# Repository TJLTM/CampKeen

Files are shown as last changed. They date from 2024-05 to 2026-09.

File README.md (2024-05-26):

# CampKeen
An OpenSource RV monitoring hardware project. Currently i'm targeting my setup but leaving enough to adapt to other systems. This will allow a central place to monitor all of the various things in an RV and will be able to be integrated with an external system like Homeassistant (when I get to that it will have a separate Repo for the component) or custom setups. As well control some things around the RV. Like in this case, i have small holding tanks and to keep them from overflowing i have added waterpump and city (external water hook up control) in both the bathroom and in the kitchen. This does not have a wifi or ethernet capability. This is RS232 or USB (via the MEGA2560) device only. 

What this can monitor: 
1. Holding Tanks - Grey/Sewage via galvanic sensors (posts in the tank) these are the ones i'm using (https://www.amazon.com/gp/product/B07YVK2V2K/ref=ppx_yo_dt_b_search_asin_title?ie=UTF8&psc=1 and https://www.amazon.com/gp/product/B07SVDTHHG/ref=ppx_yo_dt_b_search_asin_title?ie=UTF8&psc=1)
2. Fresh water tank - Resistance (https://www.amazon.com/gp/product/B00Y831WPM/ref=ppx_yo_dt_b_asin_title_o07_s01?ie=UTF8&th=1&psc=1)
3. Camper Battery Voltage
4. Power/Energy Monitoring (https://github.com/CircuitSetup/Split-Single-Phase-Energy-Meter)
5. Tempetures around the RV especially and Fridge and Freezer (https://www.amazon.com/gp/product/B087NMHGX8/ref=ppx_yo_dt_b_asin_title_o07_s01?ie=UTF8&psc=1)
6. Generator Temps (https://www.amazon.com/gp/product/B071DVVZHC/ref=ppx_yo_dt_b_search_asin_title?ie=UTF8&psc=1) 
7. Generator Fuel Pressure (https://www.amazon.com/gp/product/B07N8SX347/ref=ppx_yo_dt_b_search_asin_title?ie=UTF8&th=1 becareful of these they may or may not be DOA or last only a few weeks depending i haven't found a good source that isn't a crap shoot) 
8. LPG tank level - No link as this is the original tank and sensor that came with the 1978 Pace Arrow it's resistence based but single wire it is similar to https://parts.unitedrv.com/products/remote-ohm-sender-lp-gas-tank-90-degree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

What this can control:
1. WaterPump
2. City Water Valve (https://www.amazon.com/gp/product/B07N6246YB/ref=ppx_yo_dt_b_asin_title_o05_s00?ie=UTF8&th=1)
I do this with push buttons (two one in the kitchen and one in the bathroom for my set up) with LEDs to let you know that the water is on. Be it the City Water or Tank Via the pump. 
i have also included a timer. that can be set for how long you would ike the water to remain on when either button is pressed.

Other Stuff
1. There are 6 spare outputs that can be used to control whatever you want 
2. Same goes for 6 spare inputs 
3. I2C output for an 20x4 LCD to display current status (https://www.amazon.com/gp/product/B07MTFDHXZ/ref=ppx_yo_dt_b_search_asin_title?ie=UTF8&psc=1)
4. Siren to alert when the tanks are full
5. Warning LED (This and the siren can be programmed for other items for warnings) 
6. 2 Spare Buffered ADCs with POTs 

Some Specs and Installation Notes: 
1. I designed this for 12Vdc systems only so i'm not sure if it would work on a 24Vdc system might. might not. 
2. The Inputs are buffered and you can just supply 12Vdc in as a logical 'On' 
3. Outputs, Althought technically you could power the waterpump directly off of the unit. this is not recommended. nor encouraged in any way, shape or form. These outputs are used to trigger remove 12Vdc relays like the following: https://www.summitracing.com/parts/pco-5591pt

currently working on https://github.com/TJLTM/CampKeen-HomeAssistant-Custom-Integration this may roll into a true python package later on to handle communication 

FUTURE: 
Better docs with installatioin pictures for my setup. 

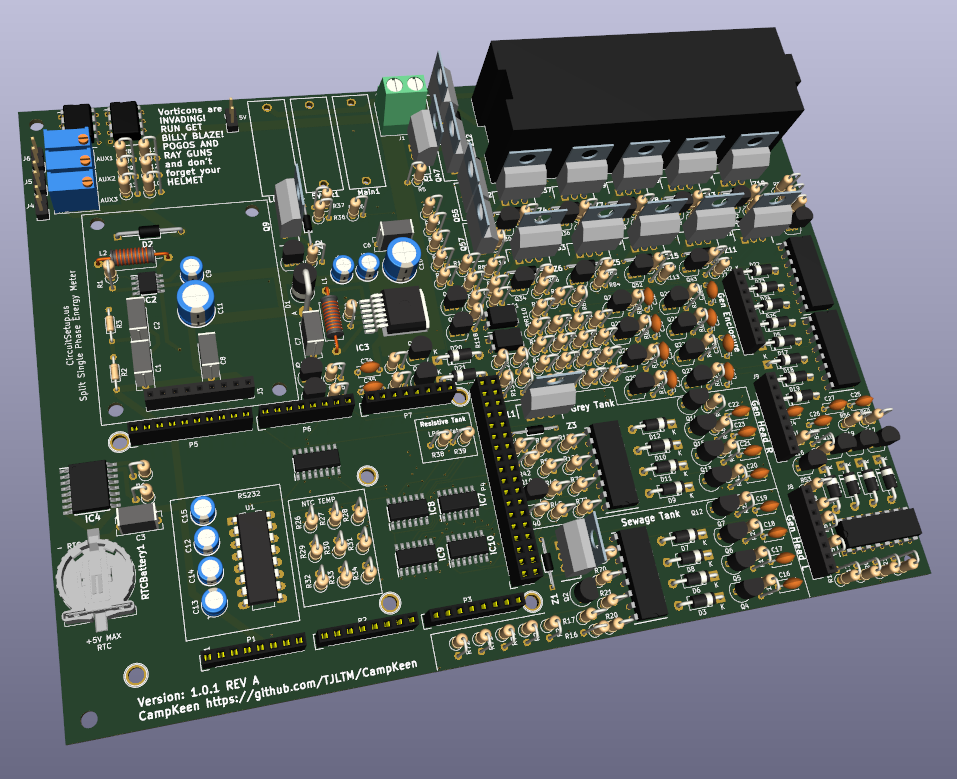
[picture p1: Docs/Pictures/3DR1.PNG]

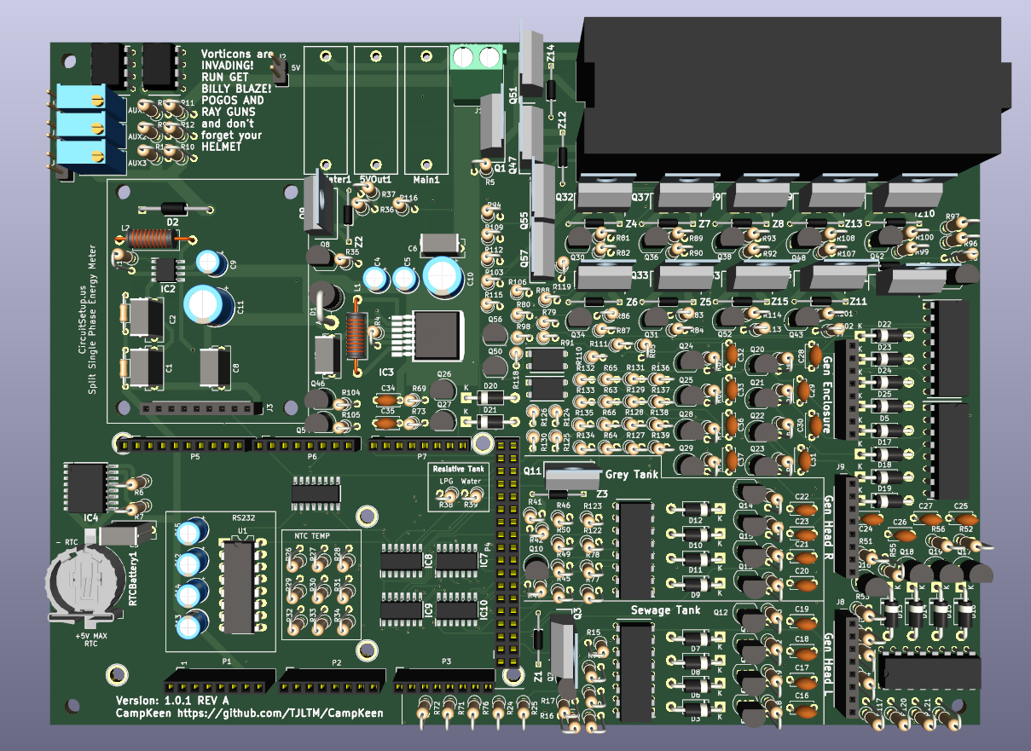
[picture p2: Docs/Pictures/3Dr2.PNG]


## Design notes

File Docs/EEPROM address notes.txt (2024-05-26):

Memory Address in EEPROM
1 - Units
2 - ACENMON on Boot - Data to be stored int 0,1
3 - 
4 - Streaming on Boot for USB Serial - Data to be sotred int 0,1
5 - Streaming on Boot for RS232 Serial - Data to be sotred int 0,1
6 - Energy Monitoring Frequency Data to be stored 50,60 
7 - Energy Monitoring Single Leg or Both Legs of 240 Data to be Stored 1,2
8 - Voltage Gain Upper Byte 
9 - Voltage Gain Lower Byte 
10 - CurrentGainCT1 Upper Byte
11 - CurrentGainCT1 Lower Byte
12 - CurrentGainCT2 Upper Byte
13 - CurrentGainCT2 Lower Byte
14 - PGAGain Upper Byte
15 - PGAGain Lower Byte
16 - WaterPumpSense on Boot - Data to be stored int 0,1
17 - WaterSourceOverRidee On Boot - Data to be stored in 0,1
18 - Kitchen Water Duration - Data to be stored Seconds in int (Upper Byte)
19 - Kitchen Water Duration - Data to be stored Seconds in int (Lower Byte)
20 - Bathroom Water Duration - Data to be stored Seconds in int (Upper Byte) 
21 - Bathroom Water Duration - Data to be stored Seconds in int (Lower Byte)

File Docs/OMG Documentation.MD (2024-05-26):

Introduction 

this project started with the lack of a way to monitor the systems within the RV I Have. this has lead to messes and headaches I no longer want to deal with and the fact that I'm somewhat smart (contrary to popular belief). I'm going to solve this problem with Electrical design and code. Mostly when I started this i wanted to be able to have a local system to monitor the various systems. NOw it's kind of grown into "I'm going to hook this up to xx so that i don't have to really do that much work and i can view it remotely". this is a mobile. techno nomad's dream come true. 

As I stated in the README. This is targeting my setup but if enough people like it then i'll work with you on getting your stuff setup. well until i loose interest if i'm not getting paid. Deal with it. but generally i'm pretty helpful because i enjoy this type of stuff. cause if i didn't i wouldn't be doing this. 

Table of contents
1. Sensors: Their Designs and Purposes 
2. FW workflows and quirks 
3. Installation information 

Sensors - Grey and Sewage Tanks 

Sensors - NTC Tempeture 

Sensors - Water Tank

Sensors - LPG Tank 

Sensors - Fuel Pressure 

Sensors - Contact inputs 

Sensors -

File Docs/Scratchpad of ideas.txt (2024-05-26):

remove LCD backlight control and dimming local to the LCD (offload from campkeen)
get serial Port3 free as to be used for ESP32 connection 
look at tanks and see if holding tanks can be consolidated to one fet for power 
if i have to free up space on the PCB, look into removing some of the hex inverters (SN7404)

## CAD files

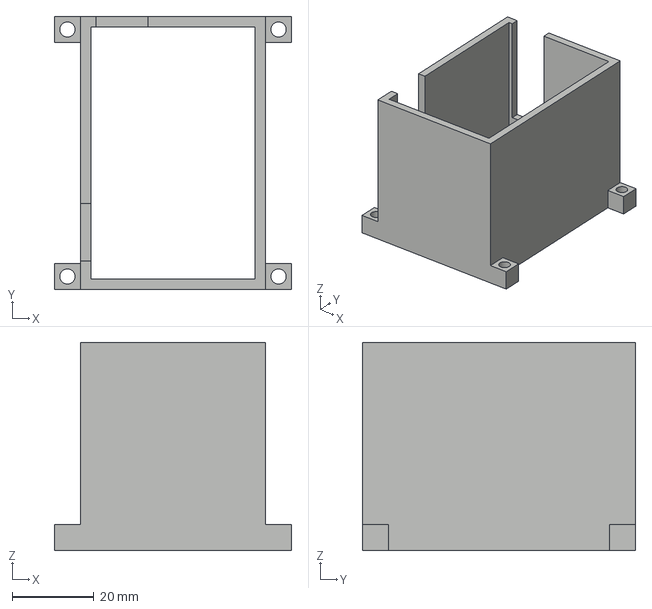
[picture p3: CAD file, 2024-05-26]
3D Parts/Transformer 157041 mount.FCStd
57.9 x 66.7 x 50.8 mm

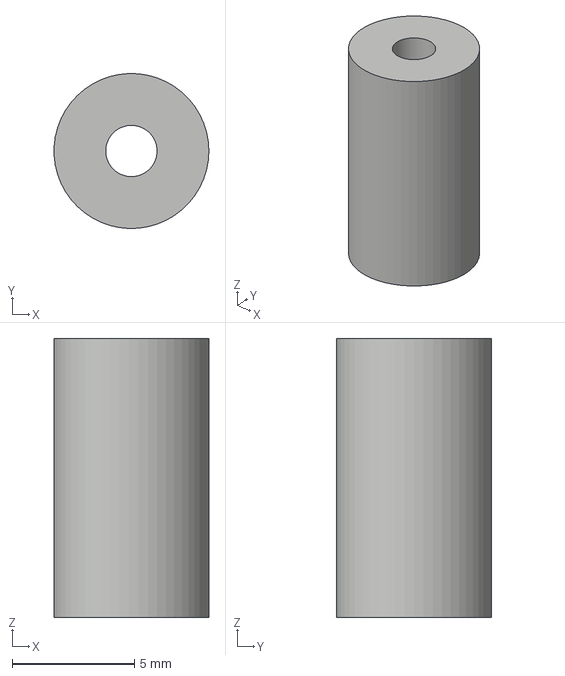
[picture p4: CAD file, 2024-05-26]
3D Parts/EnergyMonitorSpacer.FCStd
6.34 x 6.35 x 11.4 mm

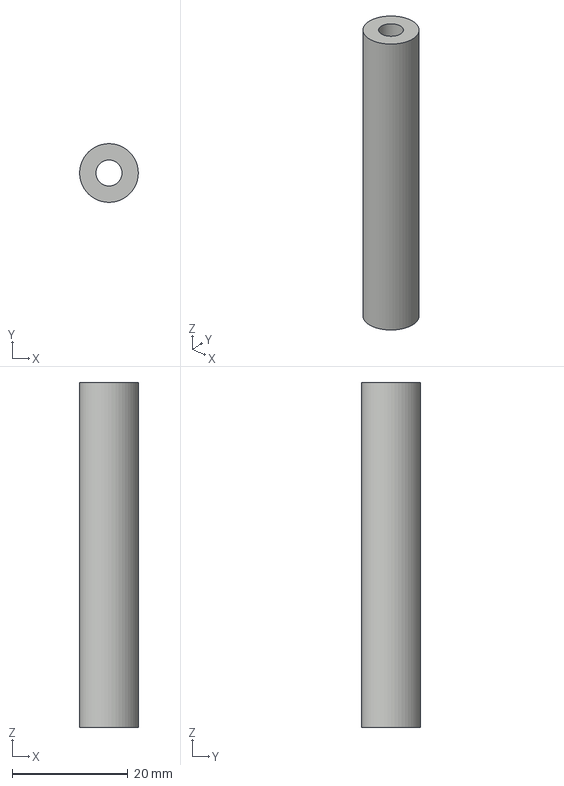
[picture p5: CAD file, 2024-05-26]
3D Parts/PanelStandOff.FCStd
10.2 x 10.2 x 59.7 mm

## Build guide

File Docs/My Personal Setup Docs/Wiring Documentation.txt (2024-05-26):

Water Pump
-- White -- Water pump sense 
-- Green -- Water Pump Relay
-- black -- NC
-- red -- NC 

Sewage/Grey 
-- Blue --1/4
-- Brown -- 1/2
-- Green -- 3/4
-- White - Full
-- Red/Black -- 12v Power

Bathroom 
-- Red -- LED Positive 
-- White -- Button Positive
-- Green -- Button input to CampKeen
-- Black -- LED GND

Kitchen 
-- Red -- LED Positive
-- Black -- LED GND
-- White -- Button Positive
-- Green -- Button input to CampKeen

LCD/Control panel 
-- warning LED -- brown/white
-- Alarm LED/Siren -- brown
-- water source selection -- green 
-- Alarm Reset -- orange
-- Enable LCD -- green/white
-- I2C SDA -- blue
-- I2C SCL -- blue/white
-- 5V -- orange/white

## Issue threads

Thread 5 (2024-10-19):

swap power to daughter boards

TJLTM, 2024-10-19:

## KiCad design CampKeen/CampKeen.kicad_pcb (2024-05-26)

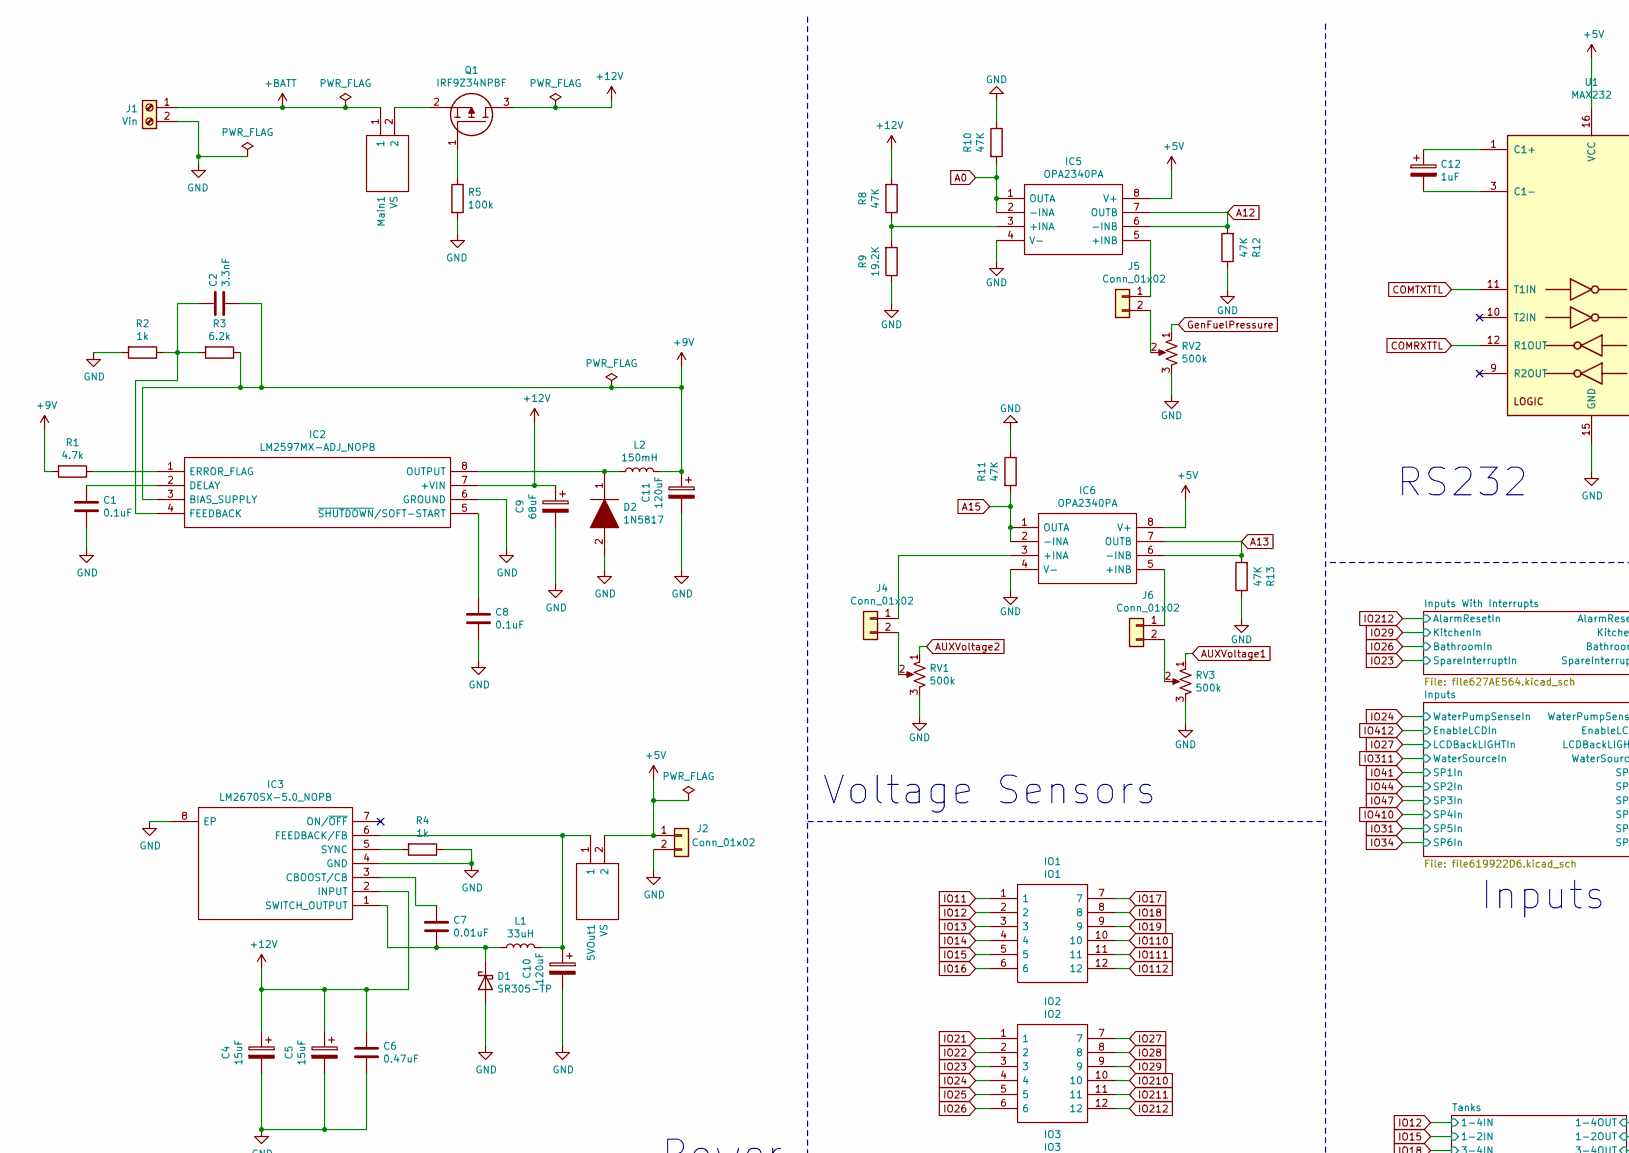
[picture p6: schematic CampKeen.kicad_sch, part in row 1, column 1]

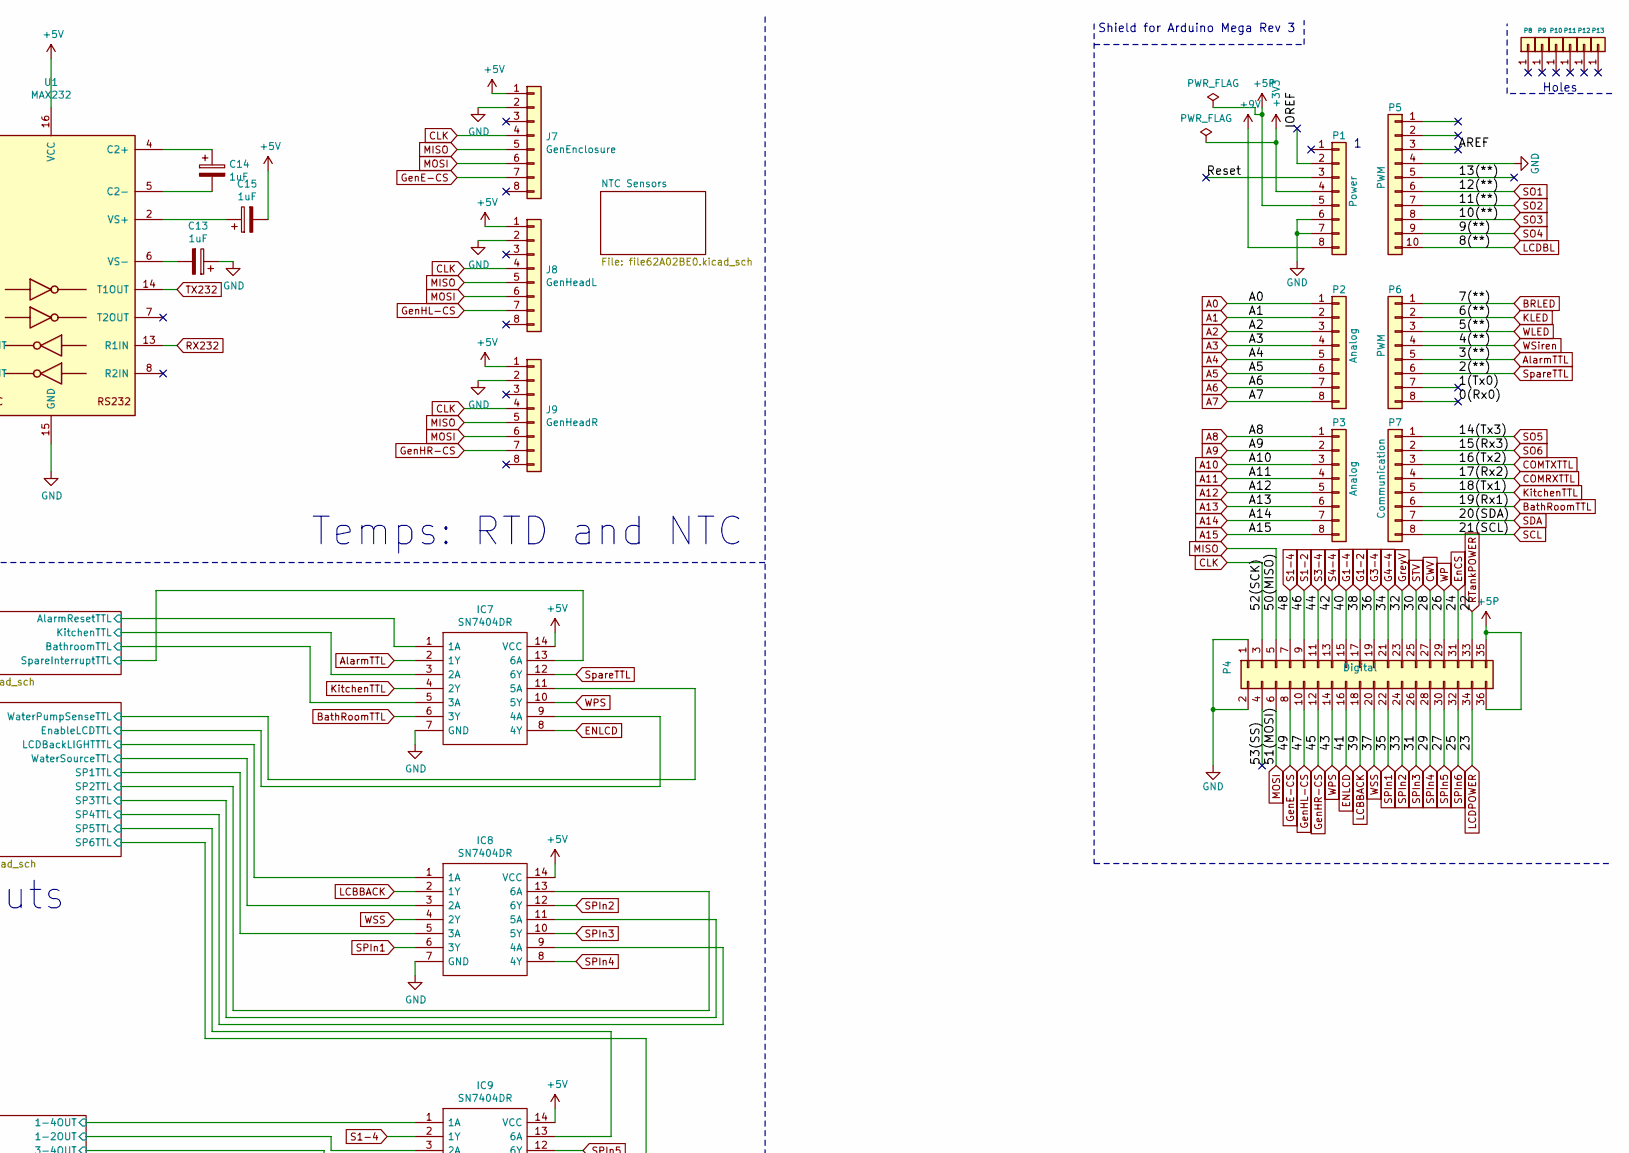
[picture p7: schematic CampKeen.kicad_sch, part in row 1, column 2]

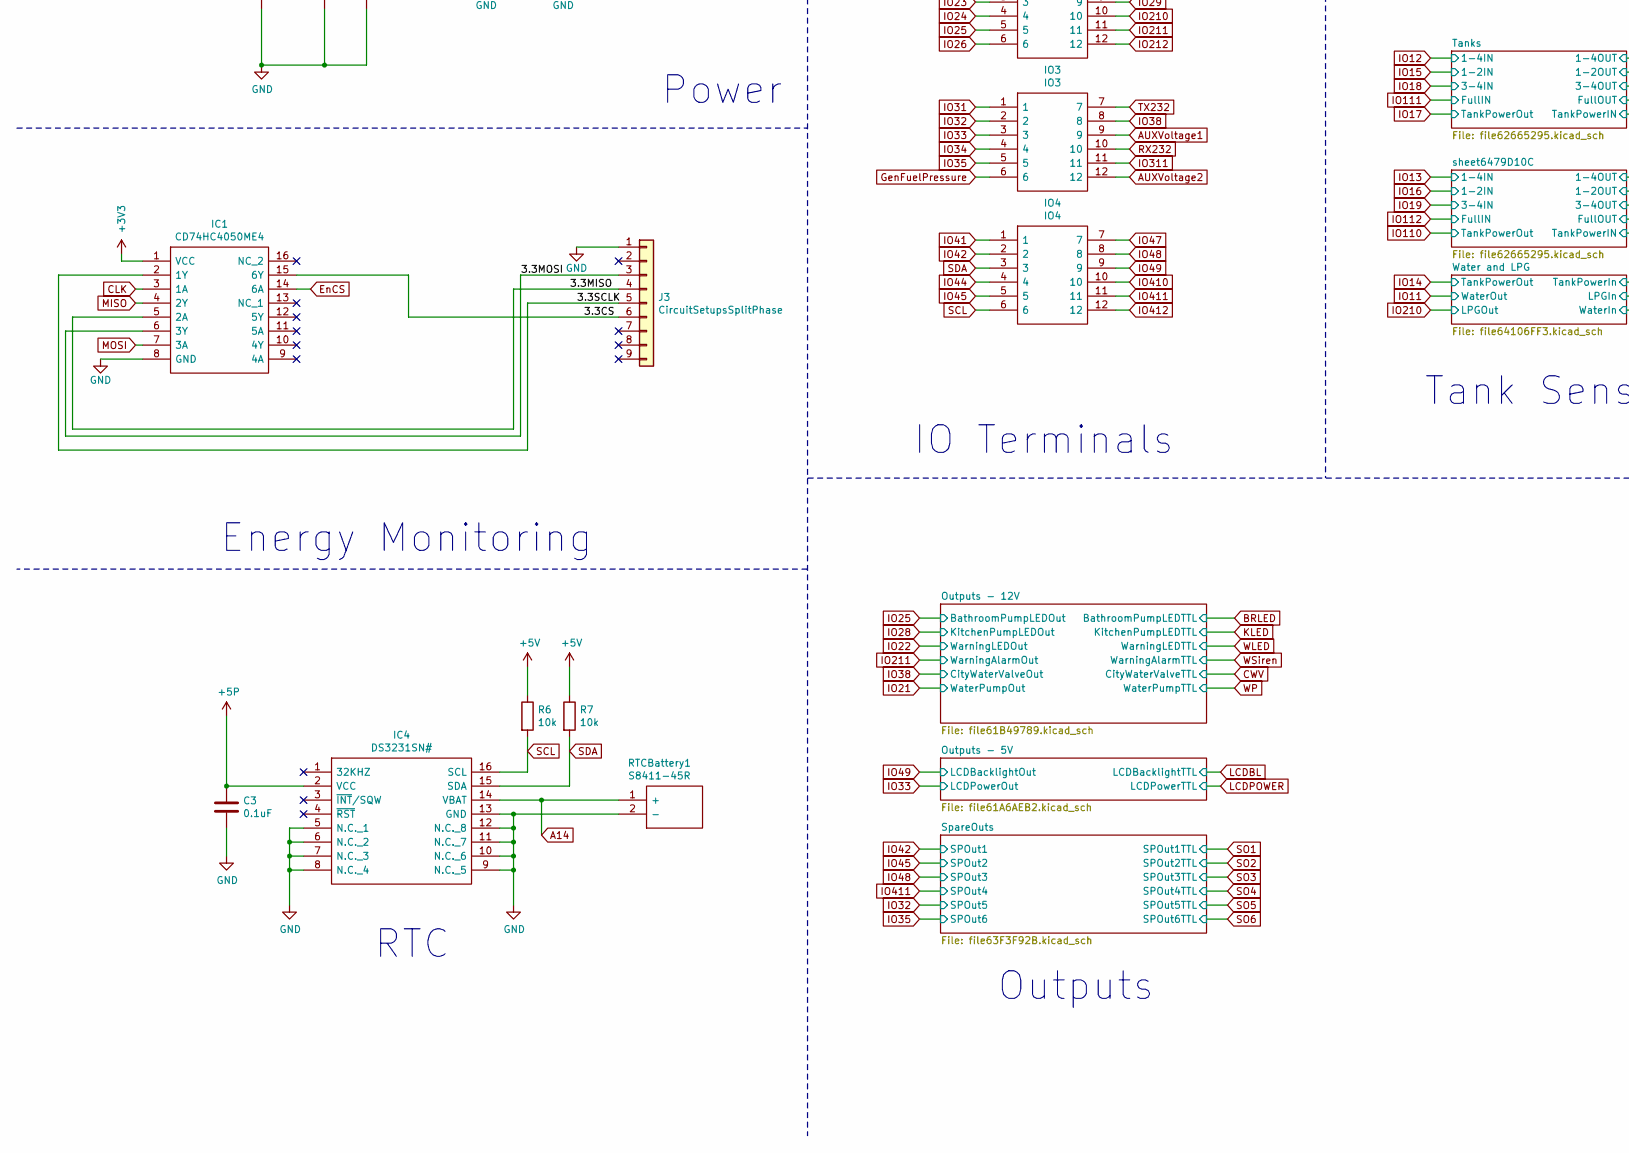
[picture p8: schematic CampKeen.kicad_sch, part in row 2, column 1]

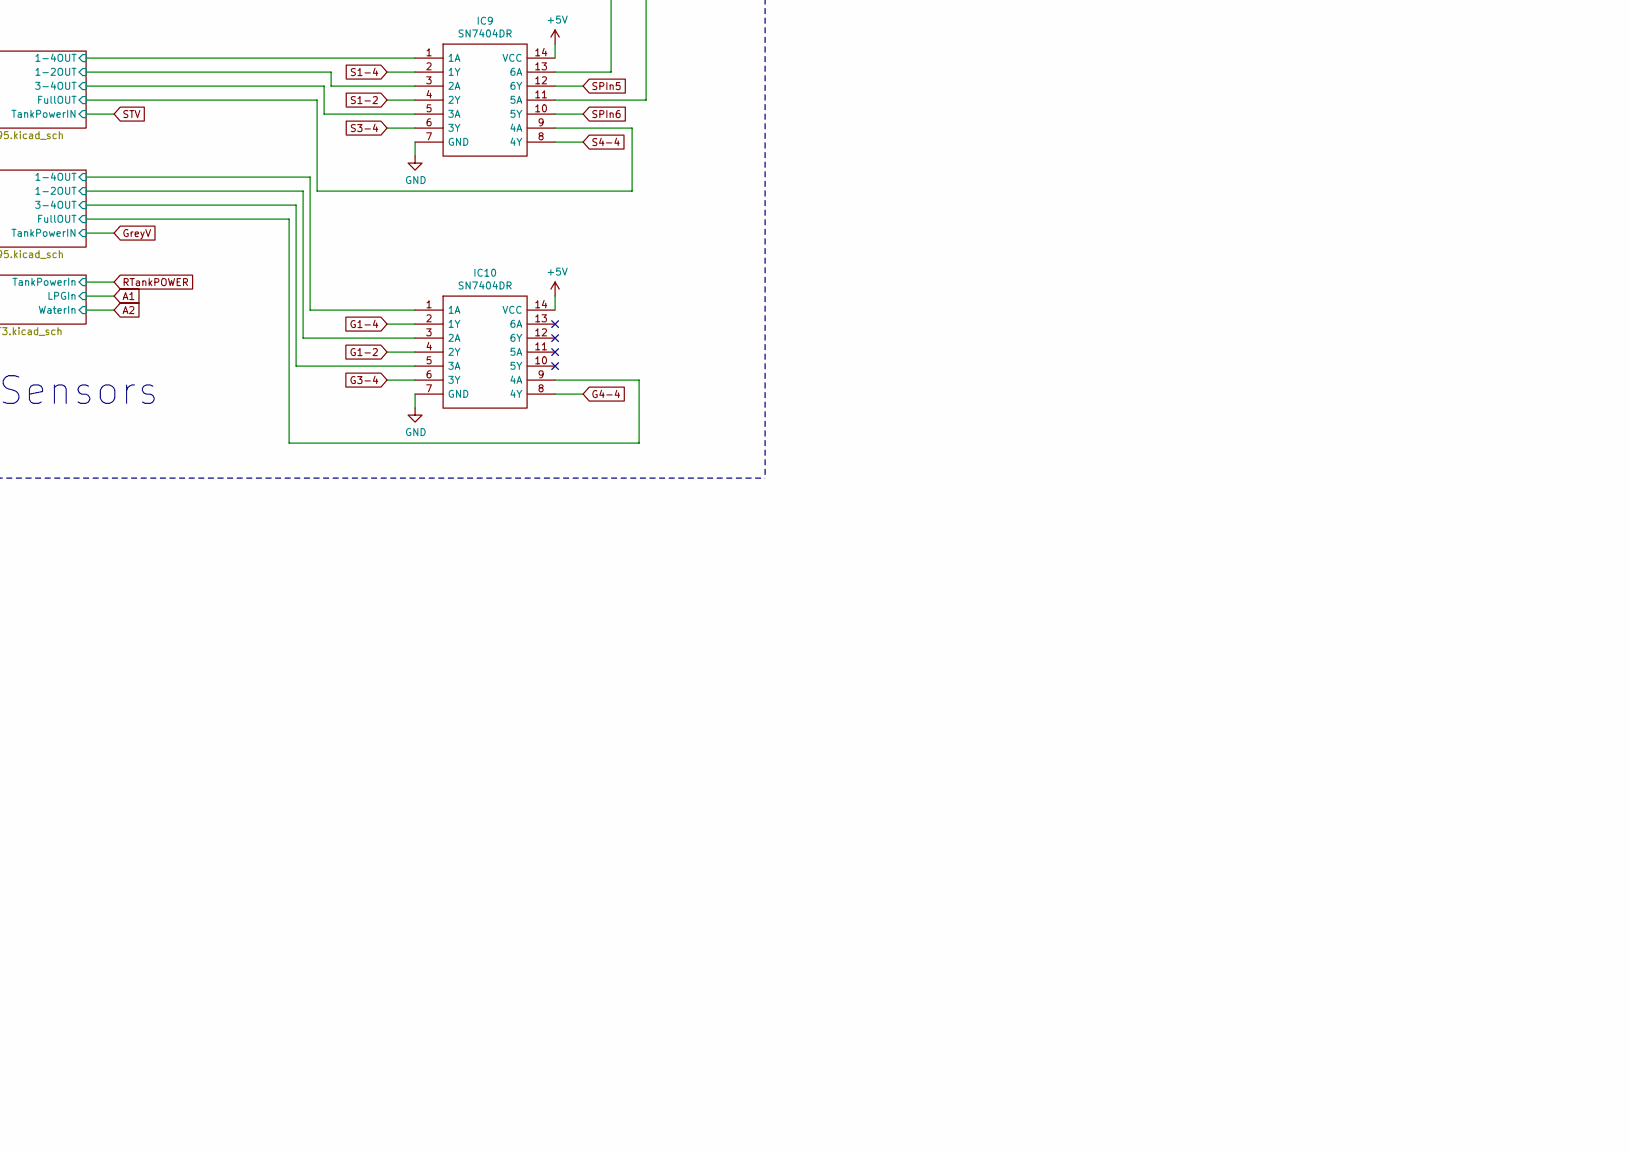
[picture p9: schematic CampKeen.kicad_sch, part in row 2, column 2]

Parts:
5VOut1: VS; BK_HTC-15M; Mouser Part Number 504-HTC-15M
C1, C3, C8: 0.1uF; C_Rect_L9.0mm_W3.6mm_P7.50mm_MKT
C2: 3.3nF; C_Rect_L9.0mm_W3.6mm_P7.50mm_MKT
C4, C5: 15uF; CP_Radial_D5.0mm_P2.50mm
C6: 0.47uF; C_Rect_L9.0mm_W3.6mm_P7.50mm_MKT
C7: 0.01uF; C_Rect_L9.0mm_W3.6mm_P7.50mm_MKT
C9: 68uF; CP_Radial_D5.0mm_P2.50mm
C10, C11: 120uF; CP_Radial_D8.0mm_P5.00mm
C12, C13, C14, C15: 1uF; CP_Radial_D5.0mm_P2.50mm
D1: SR305-TP; D_DO-201AD_P5.08mm_Vertical_AnodeUp
D2: 1N5817; DIOAD1414W86L464D238; Mouser Part Number 511-1N5817
IC1: CD74HC4050ME4; SOIC127P600X175-16N; Mouser Part Number 595-CD74HC4050ME4
IC2: LM2597MX-ADJ_NOPB; SOIC127P600X175-8N; Mouser Part Number 926-LM2597MXADJNOPB
IC3: LM2670SX-5.0_NOPB; LM2670SX50NOPB; Mouser Part Number 926-LM2670SX50NOPB
IC4: DS3231SN#; SOIC127P1032X265-16N; Mouser Part Number 700-DS3231SN#
IC5, IC6: OPA2340PA; DIP794W53P254L959H508Q8N; Mouser Part Number 595-OPA2340PA
IC7, IC8, IC9, IC10: SN7404DR; SOIC127P600X175-14N; Mouser Part Number 595-SN7404DR
IO1: IO1; 1727751; Mouser Part Number 651-1727751
IO2: IO2; 1727751; Mouser Part Number 651-1727751
IO3: IO3; 1727751; Mouser Part Number 651-1727751
IO4: IO4; 1727751; Mouser Part Number 651-1727751
J1: Vin; TerminalBlock_Phoenix_MKDS-1,5-2-5.08_1x02_P5.08mm_Horizont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
J2, J4, J5, J6: Conn_01x02; PinHeader_1x02_P2.54mm_Vertical
J3: CircuitSetupsSplitPhase; PinSocket_1x09_P2.54mm_Vertical
J7: GenEnclosure; PinSocket_1x08_P2.54mm_Vertical
J8: GenHeadL; PinSocket_1x08_P2.54mm_Vertical
J9: GenHeadR; PinSocket_1x08_P2.54mm_Vertical
L1: 33uH; L_Axial_L9.5mm_D4.0mm_P15.24mm_Horizontal_Fastron_SMCC
L2: 150mH; L_Axial_L9.5mm_D4.0mm_P15.24mm_Horizontal_Fastron_SMCC
Main1: VS; BK_HTC-15M; Mouser Part Number 504-HTC-15M
P1: Power; Socket_Strip_Arduino_1x08
P2, P3: Analog; Socket_Strip_Arduino_1x08
P4: Digital; Socket_Strip_Arduino_2x18
P5: PWM; Socket_Strip_Arduino_1x10
P6: PWM; Socket_Strip_Arduino_1x08
P7: Communication; Socket_Strip_Arduino_1x08
P8, P9, P10, P11, P12, P13: CONN_01X01; Arduino_1pin
Q1: IRF9Z34NPBF; TO254P469X1042X1967-3P; Mouser Part Number 942-IRF9Z34NPBF
R1: 4.7k; R_Axial_DIN0207_L6.3mm_D2.5mm_P2.54mm_Vertical
R2: 1k; R_Axial_DIN0204_L3.6mm_D1.6mm_P7.62mm_Horizontal
R3: 6.2k; R_Axial_DIN0204_L3.6mm_D1.6mm_P7.62mm_Horizontal
R4: 1k; R_Axial_DIN0207_L6.3mm_D2.5mm_P2.54mm_Vertical
R5: 100k; R_Axial_DIN0207_L6.3mm_D2.5mm_P2.54mm_Vertical
R6, R7: 10k; R_Axial_DIN0207_L6.3mm_D2.5mm_P2.54mm_Vertical
R8, R10, R11, R12, R13: 47K; R_Axial_DIN0207_L6.3mm_D2.5mm_P2.54mm_Vertical
R9: 19.2K; R_Axial_DIN0207_L6.3mm_D2.5mm_P2.54mm_Vertical
RTCBattery1: S8411-45R; S8411-45R_1; Mouser Part Number 855-S8411-45R
RV1, RV2, RV3: 500k; Potentiometer_Bourns_3296W_Vertical
U1: MAX232; DIP-16_W7.62mm_LongPads

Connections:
+3V3: IC1.1 (VCC), P1.4
+5P: C3.1, IC4.2 (VCC), P1.5, P4.35, P4.36
+5V: 5VOut1.2, C15.2, IC5.8 (V+), IC6.8 (V+), IC7.14 (VCC), IC8.14 (VCC), IC9.14 (VCC), IC10.14 (VCC), J2.1, J7.1, J8.1, J9.1, R6.1, R7.1, U1.16 (VCC); also elsewhere on the board
+9V: C2.2, C11.1, IC2.3 (BIAS_SUPPLY), L2.2, P1.8, R1.2, R3.1
+12V: C4.1, C5.1, C6.1, C9.1, IC2.7 (+VIN), IC3.2 (INPUT), Q1.3, R8.2; also elsewhere on the board
+BATT: J1.1, Main1.1; also elsewhere on the board
/0(Rx0): P6.8
/1(Tx0): P6.7
/3.3CS: IC1.15 (6Y), J3.6
/3.3MISO: IC1.5 (2A), J3.4
/3.3MOSI: IC1.6 (3Y), J3.3
/3.3SCLK: IC1.2 (1Y), J3.5
/13(**): P5.5
/53(SS): P4.4
/AREF: P5.3
/IOREF: P1.2
/Inputs With Interrupts/AlarmResetTTL: IC7.1 (1A); also elsewhere on the board
/Inputs With Interrupts/BathroomTTL: IC7.5 (3A); also elsewhere on the board
/Inputs With Interrupts/KitchenTTL: IC7.3 (2A); also elsewhere on the board
/Inputs With Interrupts/SpareInterruptTTL: IC7.13 (6A); also elsewhere on the board
/Inputs/EnableLCDTTL: IC7.9 (4A); also elsewhere on the board
/Inputs/LCDBackLIGHTTTL: IC8.1 (1A); also elsewhere on the board
/Inputs/SP1TTL: IC8.5 (3A); also elsewhere on the board
/Inputs/SP2TTL: IC8.13 (6A); also elsewhere on the board
/Inputs/SP3TTL: IC8.11 (5A); also elsewhere on the board
/Inputs/SP4TTL: IC8.9 (4A); also elsewhere on the board
/Inputs/SP5TTL: IC9.13 (6A); also elsewhere on the board
/Inputs/SP6TTL: IC9.11 (5A); also elsewhere on the board
/Inputs/WaterPumpSenseTTL: IC7.11 (5A); also elsewhere on the board
/Inputs/WaterSourceTTL: IC8.3 (2A); also elsewhere on the board
/Reset: P1.3
/Tanks/1-2OUT: IC9.3 (2A); also elsewhere on the board
/Tanks/1-4OUT: IC9.1 (1A); also elsewhere on the board
/Tanks/3-4OUT: IC9.5 (3A); also elsewhere on the board
/Tanks/FullOUT: IC9.9 (4A); also elsewhere on the board
/sheet6479D10C/1-2OUT: IC10.3 (2A); also elsewhere on the board
/sheet6479D10C/1-4OUT: IC10.1 (1A); also elsewhere on the board
/sheet6479D10C/3-4OUT: IC10.5 (3A); also elsewhere on the board
/sheet6479D10C/FullOUT: IC10.9 (4A); also elsewhere on the board
A0: IC5.1 (OUTA), IC5.2 (-INA), P2.1, R10.2
A1: IO2.10, P2.2; also elsewhere on the board
A2: IO1.1, P2.3; also elsewhere on the board
A3: P2.4; also elsewhere on the board
A4: P2.5; also elsewhere on the board
A5: P2.6; also elsewhere on the board
A6: P2.7; also elsewhere on the board
A7: P2.8; also elsewhere on the board
A8: P3.1; also elsewhere on the board
A9: P3.2; also elsewhere on the board
A10: P3.3; also elsewhere on the board
A11: P3.4; also elsewhere on the board
A12: IC5.6 (-INB), IC5.7 (OUTB), P3.5, R12.2
A13: IC6.6 (-INB), IC6.7 (OUTB), P3.6, R13.2
A14: IC4.14 (VBAT), P3.7, RTCBattery1.1 (+)
A15: IC6.1 (OUTA), IC6.2 (-INA), P3.8, R11.2
AUXVoltage1: IO3.9, RV3.1
AUXVoltage2: IO3.12, RV1.1
AlarmTTL: IC7.2 (1Y), P6.5
BRLED: P6.1; also elsewhere on the board
BathRoomTTL: IC7.6 (3Y), P7.6
CLK: IC1.3 (1A), J7.4, J8.4, J9.4, P4.3
COMRXTTL: P7.4, U1.12 (R1OUT)
COMTXTTL: P7.3, U1.11 (T1IN)
CWV: P4.27; also elsewhere on the board
ENLCD: IC7.8 (4Y), P4.16
EnCS: IC1.14 (6A), P4.31
G1-2: IC10.4 (2Y), P4.17
G1-4: IC10.2 (1Y), P4.15
G3-4: IC10.6 (3Y), P4.19
G4-4: IC10.8 (4Y), P4.21
GND: C1.2, C3.2, C4.2, C5.2, C6.2, C8.2, C9.2, C10.2, C11.2, C13.1, D1.2 (A), D2.2, IC1.8 (GND), IC2.6 (GROUND), IC3.4 (GND), IC3.8 (EP), IC4.5 (N.C._1), IC4.6 (N.C._2), IC4.7 (N.C._3), IC4.8 (N.C._4), IC4.9 (N.C._5), IC4.10 (N.C._6), IC4.11 (N.C._7), IC4.12 (N.C._8), IC4.13 (GND), IC5.4 (V-), IC6.4 (V-), IC7.7 (GND), IC8.7 (GND), IC9.7 (GND), IC10.7 (GND), J1.2, J2.2, J3.1, J7.2, J8.2, J9.2, P1.6, P1.7, P4.1, P4.2, P5.4, R2.2, R4.1, R5.2, R9.1, R10.1, R11.1, R12.1, R13.1, RTCBattery1.2 (-), RV1.3, RV2.3, RV3.3, U1.15 (GND); also elsewhere on the board
GenE-CS: J7.7, P4.8
GenFuelPressure: IO3.6, RV2.1
GenHL-CS: J8.7, P4.10
GenHR-CS: J9.7, P4.12
GreyV: P4.23; also elsewhere on the board
IO12: IO1.2; also elsewhere on the board
IO13: IO1.3; also elsewhere on the board
IO14: IO1.4; also elsewhere on the board
IO15: IO1.5; also elsewhere on the board
IO16: IO1.6; also elsewhere on the board
IO17: IO1.7; also elsewhere on the board
IO18: IO1.8; also elsewhere on the board
IO19: IO1.9; also elsewhere on the board
IO21: IO2.1; also elsewhere on the board
IO22: IO2.2; also elsewhere on the board
IO23: IO2.3; also elsewhere on the board
IO24: IO2.4; also elsewhere on the board
IO25: IO2.5; also elsewhere on the board
IO26: IO2.6; also elsewhere on the board
IO27: IO2.7; also elsewhere on the board
IO28: IO2.8; also elsewhere on the board
IO29: IO2.9; also elsewhere on the board
IO31: IO3.1; also elsewhere on the board
IO32: IO3.2; also elsewhere on the board
IO33: IO3.3; also elsewhere on the board
IO34: IO3.4; also elsewhere on the board
IO35: IO3.5; also elsewhere on the board
IO38: IO3.8; also elsewhere on the board
IO41: IO4.1; also elsewhere on the board
IO42: IO4.2; also elsewhere on the board
IO44: IO4.4; also elsewhere on the board
IO45: IO4.5; also elsewhere on the board
IO47: IO4.7; also elsewhere on the board
IO48: IO4.8; also elsewhere on the board
IO49: IO4.9; also elsewhere on the board
IO110: IO1.10; also elsewhere on the board
IO111: IO1.11; also elsewhere on the board
IO112: IO1.12; also elsewhere on the board
IO211: IO2.11; also elsewhere on the board
IO212: IO2.12; also elsewhere on the board
IO311: IO3.11; also elsewhere on the board
IO410: IO4.10; also elsewhere on the board
IO411: IO4.11; also elsewhere on the board
IO412: IO4.12; also elsewhere on the board
KLED: P6.2; also elsewhere on the board
KitchenTTL: IC7.4 (2Y), P7.5
LCBBACK: IC8.2 (1Y), P4.18
LCDBL: P5.10; also elsewhere on the board
LCDPOWER: P4.34; also elsewhere on the board
MISO: IC1.4 (2Y), J7.5, J8.5, J9.5, P4.5
MOSI: IC1.7 (3A), J7.6, J8.6, J9.6, P4.6
unnamed: 5VOut1.1, C10.1, IC3.6 (FEEDBACK/FB), L1.2
unnamed: C1.1, IC2.2 (DELAY)
unnamed: C2.1, IC2.4 (FEEDBACK), R2.1, R3.2
unnamed: C7.1, IC3.3 (CBOOST/CB)
unnamed: C7.2, D1.1 (K), IC3.1 (SWITCH_OUTPUT), L1.1
unnamed: C8.1, IC2.5 (~SHUTDOWN/SOFT-START)
unnamed: C12.1, U1.1 (C1+)
unnamed: C12.2, U1.3 (C1-)
unnamed: C13.2, U1.6 (VS-)
unnamed: C14.1, U1.4 (C2+)
unnamed: C14.2, U1.5 (C2-)
unnamed: C15.1, U1.2 (VS+)
unnamed: D2.1, IC2.8 (OUTPUT), L2.1
unnamed: IC2.1 (ERROR_FLAG), R1.1
unnamed: IC3.5 (SYNC), R4.2
unnamed: IC5.3 (+INA), R8.1, R9.2
unnamed: IC5.5 (+INB), J5.1
unnamed: IC6.3 (+INA), J4.1
unnamed: IC6.5 (+INB), J6.1
unnamed: J4.2, RV1.2
unnamed: J5.2, RV2.2
unnamed: J6.2, RV3.2
unnamed: Main1.2, Q1.2
unnamed: Q1.1, R5.1
RTankPOWER: P4.33; also elsewhere on the board
RX232: IO3.10, U1.13 (R1IN)
S1-2: IC9.4 (2Y), P4.9
S1-4: IC9.2 (1Y), P4.7
S3-4: IC9.6 (3Y), P4.11
S4-4: IC9.8 (4Y), P4.13
SCL: IC4.16 (SCL), IO4.6, P7.8, R6.2
SDA: IC4.15 (SDA), IO4.3, P7.7, R7.2
SO1: P5.6; also elsewhere on the board
SO2: P5.7; also elsewhere on the board
SO3: P5.8; also elsewhere on the board
SO4: P5.9; also elsewhere on the board
SO5: P7.1; also elsewhere on the board
SO6: P7.2; also elsewhere on the board
SPIn1: IC8.6 (3Y), P4.22
SPIn2: IC8.12 (6Y), P4.24
SPIn3: IC8.10 (5Y), P4.26
SPIn4: IC8.8 (4Y), P4.28
SPIn5: IC9.12 (6Y), P4.30
SPIn6: IC9.10 (5Y), P4.32
STV: P4.25; also elsewhere on the board
SpareTTL: IC7.12 (6Y), P6.6
TX232: IO3.7, U1.14 (T1OUT)
WLED: P6.3; also elsewhere on the board
WP: P4.29; also elsewhere on the board
WPS: IC7.10 (5Y), P4.14
WSS: IC8.4 (2Y), P4.20
WSiren: P6.4; also elsewhere on the board

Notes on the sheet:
Outputs
Energy Monitoring
Temps: RTD and NTC
RTC
Holes
Tank Sensors
Voltage Sensors
Shield for Arduino Mega Rev 3
Inputs
Power
RS232
IO Terminals

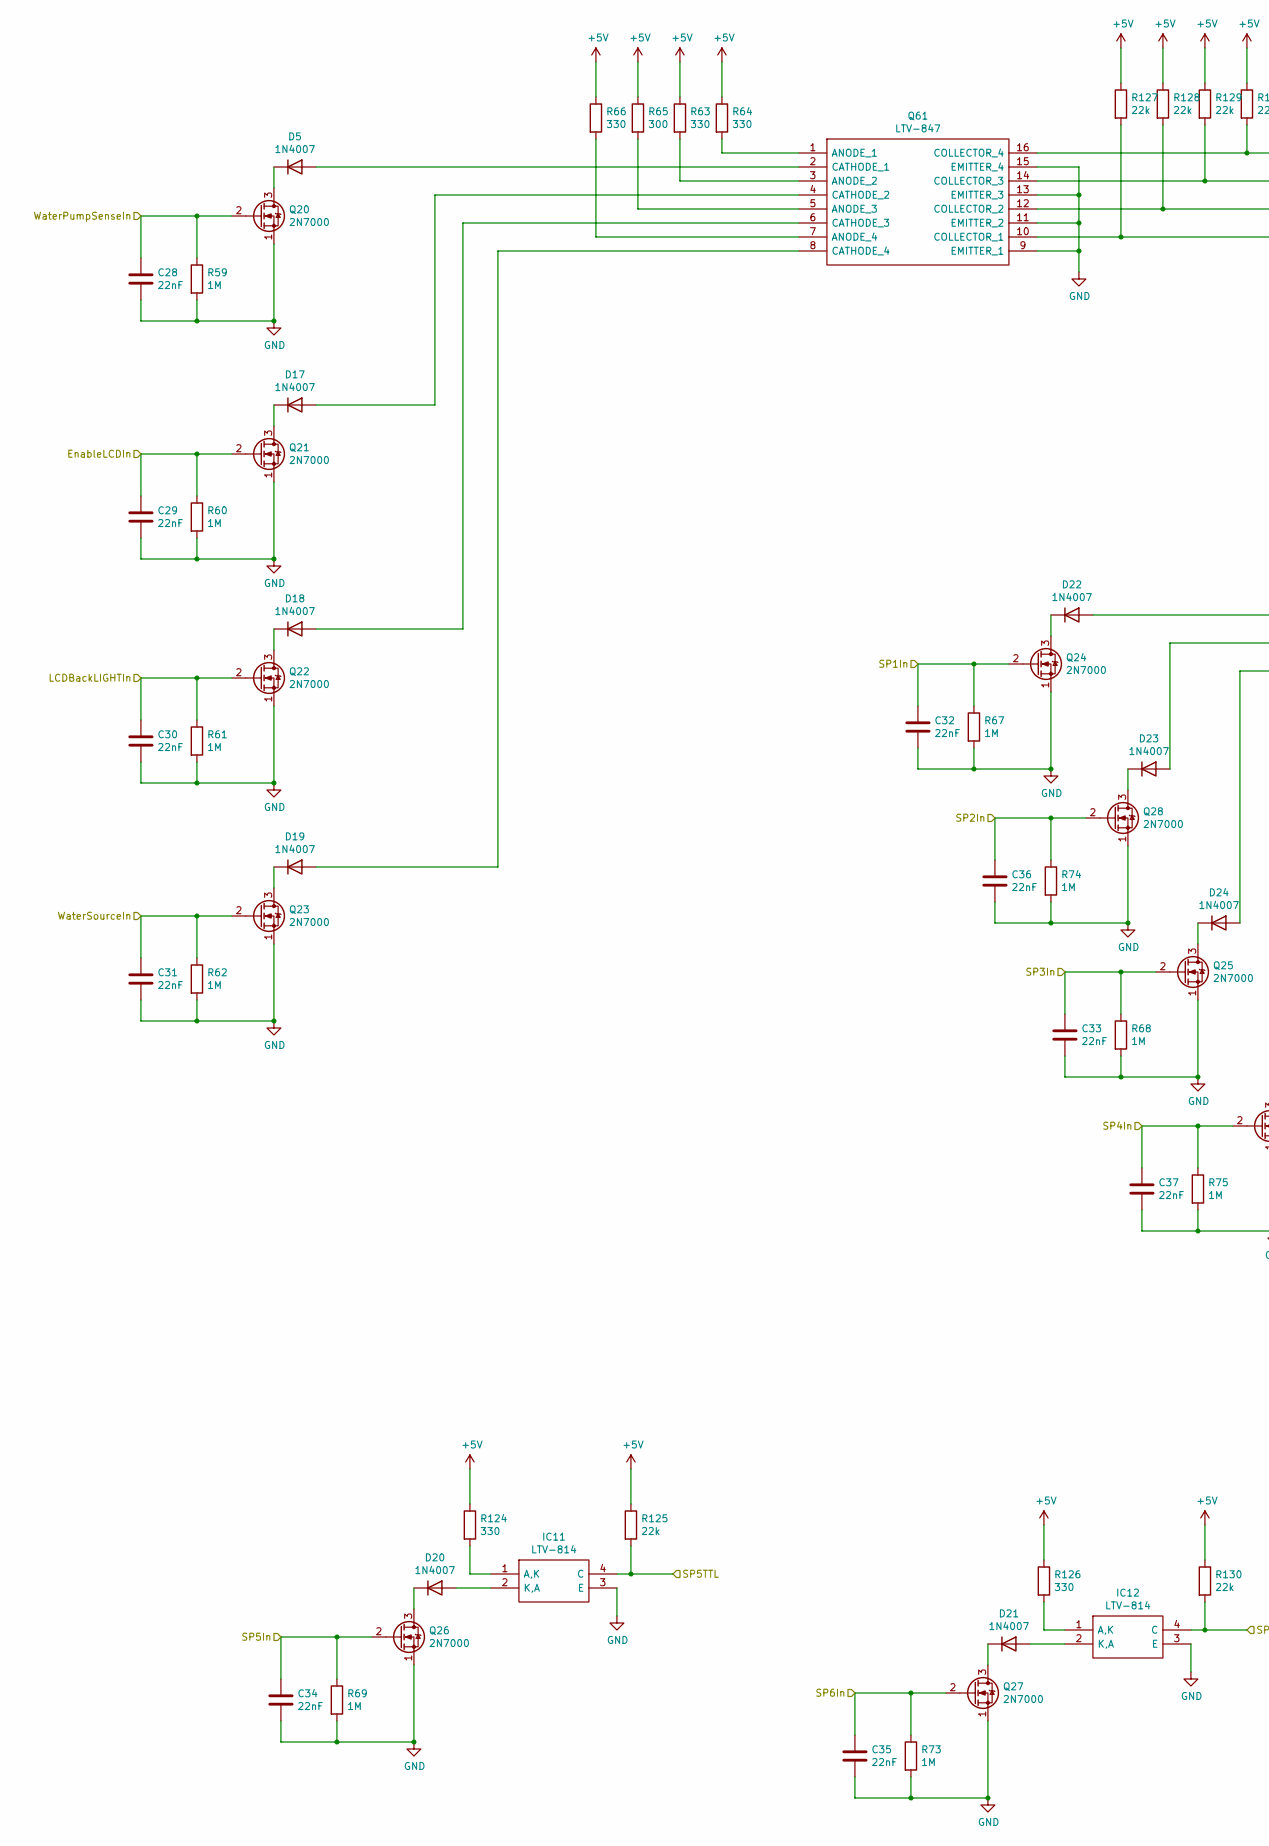
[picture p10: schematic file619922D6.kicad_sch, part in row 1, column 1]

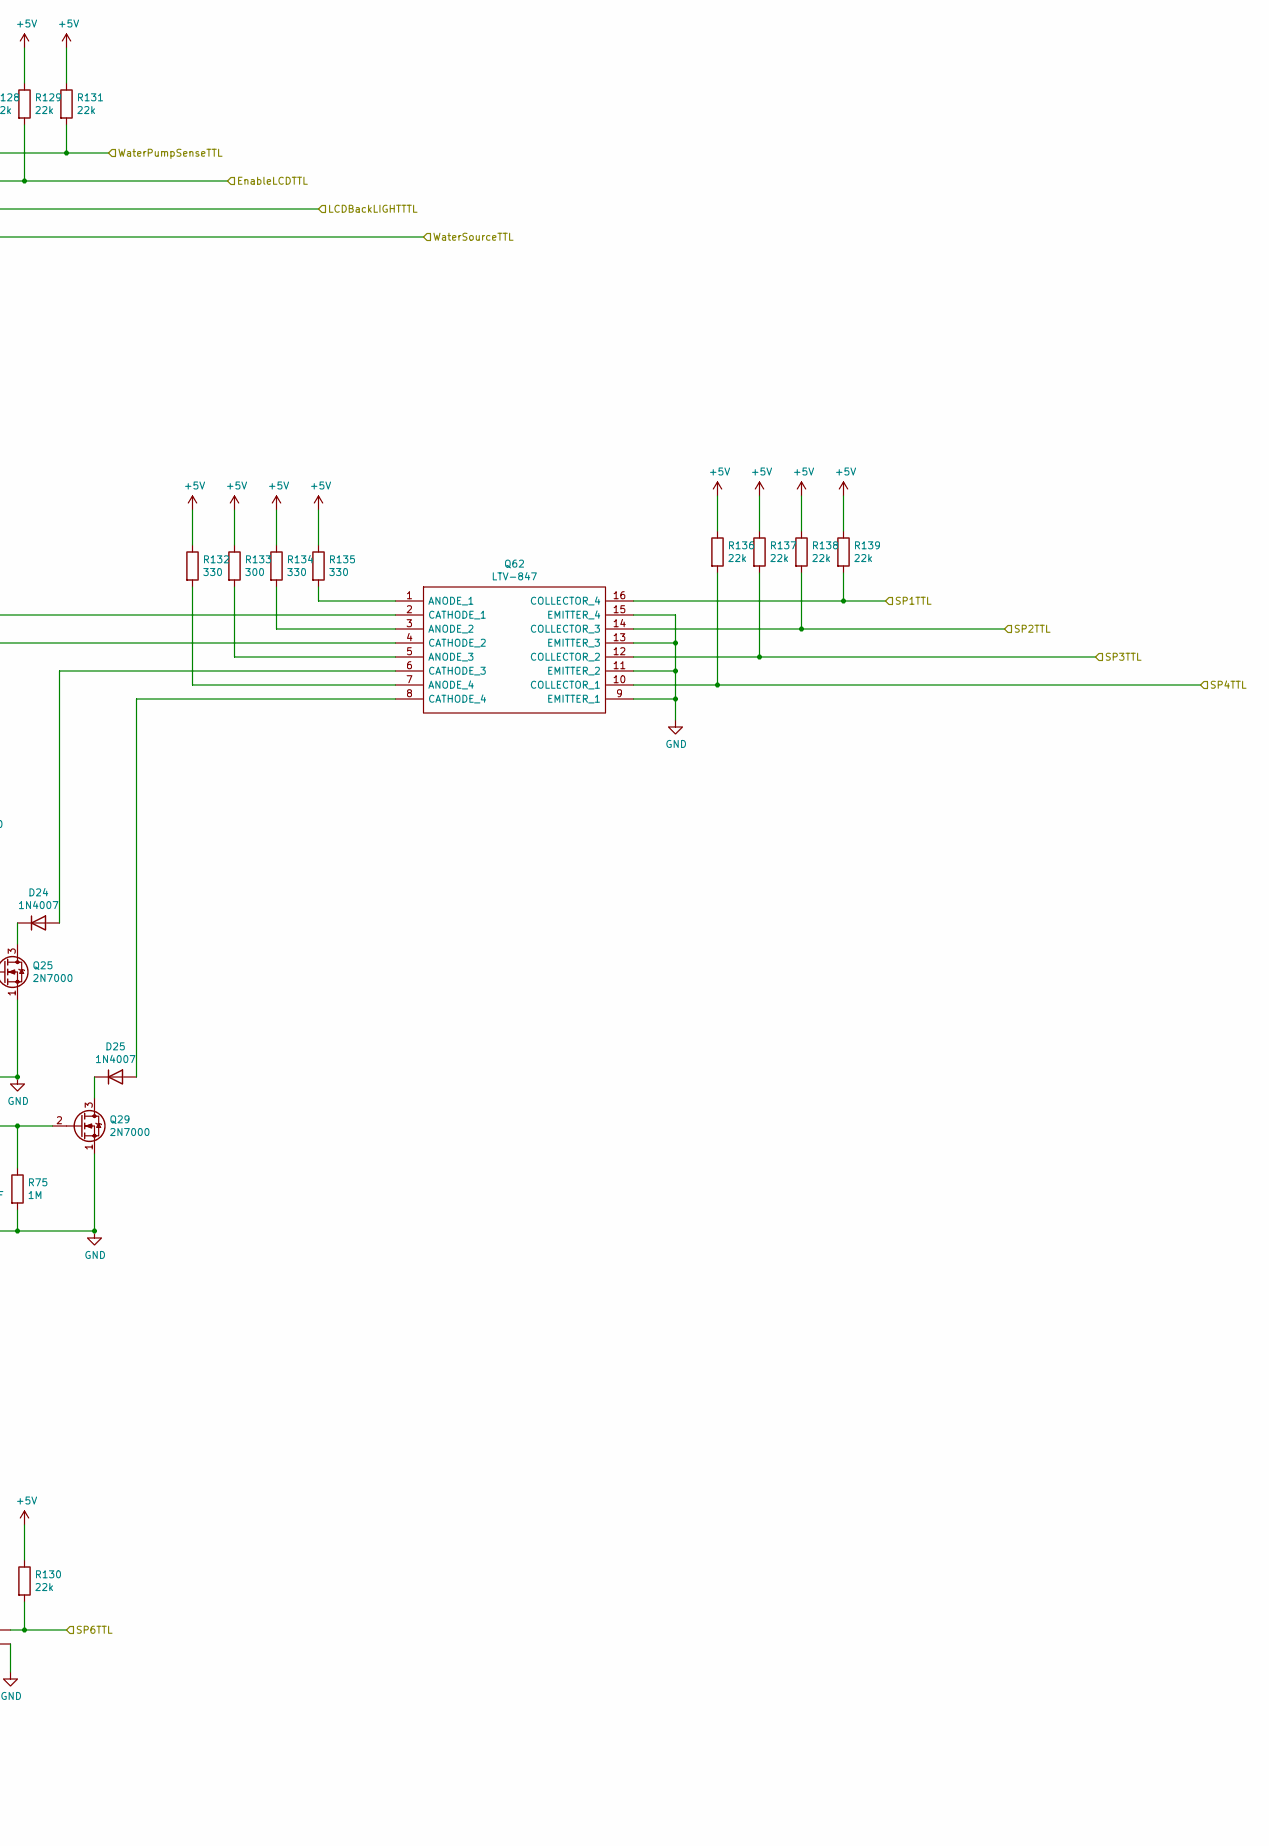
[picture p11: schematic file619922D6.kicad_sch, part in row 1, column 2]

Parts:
C28, C29, C30, C31, C32, C33, C34, C35, C36, C37: 22nF; C_Disc_D4.7mm_W2.5mm_P5.00mm
D5, D17, D18, D19, D20, D21, D22, D23, D24, D25: 1N4007; D_DO-41_SOD81_P10.16mm_Horizontal
IC11, IC12: LTV-814; DIP762W60P254L460H450Q4N; Mouser Part Number 859-LTV-814
Q20, Q21, Q22, Q23, Q24, Q25, Q26, Q27, Q28, Q29: 2N7000; TO-92_Inline
Q61, Q62: LTV-847; DIP762W60P254L1984H450Q16N; Mouser Part Number 859-LTV-847
R59, R60, R61, R62, R67, R68, R69, R73, R74, R75: 1M; R_Axial_DIN0207_L6.3mm_D2.5mm_P2.54mm_Vertical
R63, R64, R66, R124, R126, R132, R134, R135: 330; R_Axial_DIN0207_L6.3mm_D2.5mm_P2.54mm_Vertical
R65, R133: 300; R_Axial_DIN0207_L6.3mm_D2.5mm_P2.54mm_Vertical
R125, R127, R128, R129, R130, R131, R136, R137, R138, R139: 22k; R_Axial_DIN0207_L6.3mm_D2.5mm_P2.54mm_Vertical

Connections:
+5V: R63.1, R64.1, R65.1, R66.1, R124.1, R125.1, R126.1, R127.1, R128.1, R129.1, R130.1, R131.1, R132.1, R133.1, R134.1, R135.1, R136.1, R137.1, R138.1, R139.1; also elsewhere on the board
/Inputs/EnableLCDTTL: Q61.14 (COLLECTOR_3), R129.2; also elsewhere on the board
/Inputs/LCDBackLIGHTTTL: Q61.12 (COLLECTOR_2), R128.2; also elsewhere on the board
/Inputs/SP1TTL: Q62.16 (COLLECTOR_4), R139.2; also elsewhere on the board
/Inputs/SP2TTL: Q62.14 (COLLECTOR_3), R138.2; also elsewhere on the board
/Inputs/SP3TTL: Q62.12 (COLLECTOR_2), R137.2; also elsewhere on the board
/Inputs/SP4TTL: Q62.10 (COLLECTOR_1), R136.2; also elsewhere on the board
/Inputs/SP5TTL: IC11.4 (C), R125.2; also elsewhere on the board
/Inputs/SP6TTL: IC12.4 (C), R130.2; also elsewhere on the board
/Inputs/WaterPumpSenseTTL: Q61.16 (COLLECTOR_4), R131.2; also elsewhere on the board
/Inputs/WaterSourceTTL: Q61.10 (COLLECTOR_1), R127.2; also elsewhere on the board
GND: C28.2, C29.2, C30.2, C31.2, C32.2, C33.2, C34.2, C35.2, C36.2, C37.2, IC11.3 (E), IC12.3 (E), Q20.1 (S), Q21.1 (S), Q22.1 (S), Q23.1 (S), Q24.1 (S), Q25.1 (S), Q26.1 (S), Q27.1 (S), Q28.1 (S), Q29.1 (S), Q61.9 (EMITTER_1), Q61.11 (EMITTER_2), Q61.13 (EMITTER_3), Q61.15 (EMITTER_4), Q62.9 (EMITTER_1), Q62.11 (EMITTER_2), Q62.13 (EMITTER_3), Q62.15 (EMITTER_4), R59.2, R60.2, R61.2, R62.2, R67.2, R68.2, R69.2, R73.2, R74.2, R75.2; also elsewhere on the board
IO24: C28.1, Q20.2 (G), R59.1; also elsewhere on the board
IO27: C30.1, Q22.2 (G), R61.1; also elsewhere on the board
IO31: C34.1, Q26.2 (G), R69.1; also elsewhere on the board
IO34: C35.1, Q27.2 (G), R73.1; also elsewhere on the board
IO41: C32.1, Q24.2 (G), R67.1; also elsewhere on the board
IO44: C36.1, Q28.2 (G), R74.1; also elsewhere on the board
IO47: C33.1, Q25.2 (G), R68.1; also elsewhere on the board
IO311: C31.1, Q23.2 (G), R62.1; also elsewhere on the board
IO410: C37.1, Q29.2 (G), R75.1; also elsewhere on the board
IO412: C29.1, Q21.2 (G), R60.1; also elsewhere on the board
unnamed: D5.1 (K), Q20.3 (D)
unnamed: D5.2 (A), Q61.2 (CATHODE_1)
unnamed: D17.1 (K), Q21.3 (D)
unnamed: D17.2 (A), Q61.4 (CATHODE_2)
unnamed: D18.1 (K), Q22.3 (D)
unnamed: D18.2 (A), Q61.6 (CATHODE_3)
unnamed: D19.1 (K), Q23.3 (D)
unnamed: D19.2 (A), Q61.8 (CATHODE_4)
unnamed: D20.1 (K), Q26.3 (D)
unnamed: D20.2 (A), IC11.2 (K,A)
unnamed: D21.1 (K), Q27.3 (D)
unnamed: D21.2 (A), IC12.2 (K,A)
unnamed: D22.1 (K), Q24.3 (D)
unnamed: D22.2 (A), Q62.2 (CATHODE_1)
unnamed: D23.1 (K), Q28.3 (D)
unnamed: D23.2 (A), Q62.4 (CATHODE_2)
unnamed: D24.1 (K), Q25.3 (D)
unnamed: D24.2 (A), Q62.6 (CATHODE_3)
unnamed: D25.1 (K), Q29.3 (D)
unnamed: D25.2 (A), Q62.8 (CATHODE_4)
unnamed: IC11.1 (A,K), R124.2
unnamed: IC12.1 (A,K), R126.2
unnamed: Q61.1 (ANODE_1), R64.2
unnamed: Q61.3 (ANODE_2), R63.2
unnamed: Q61.5 (ANODE_3), R65.2
unnamed: Q61.7 (ANODE_4), R66.2
unnamed: Q62.1 (ANODE_1), R135.2
unnamed: Q62.3 (ANODE_2), R134.2
unnamed: Q62.5 (ANODE_3), R133.2
unnamed: Q62.7 (ANODE_4), R132.2

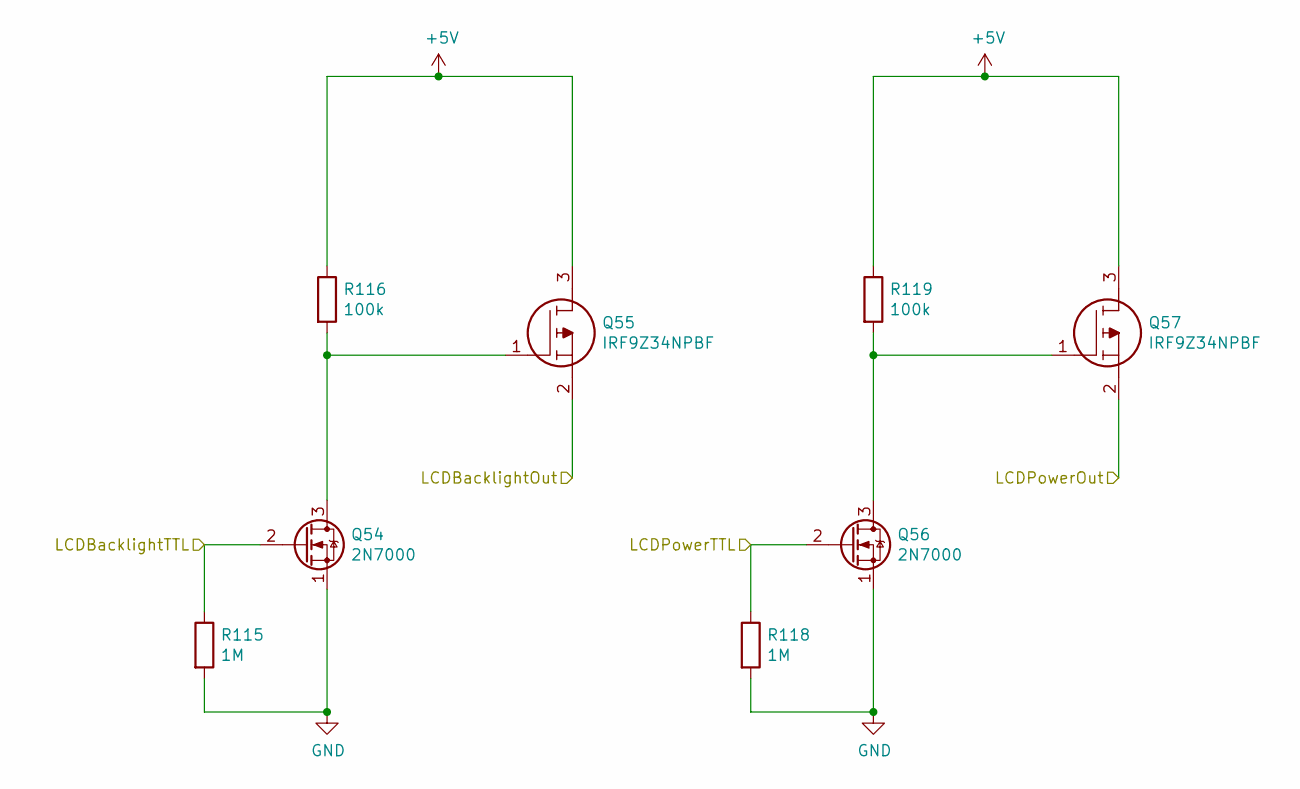
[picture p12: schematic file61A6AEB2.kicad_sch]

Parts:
Q54, Q56: 2N7000; TO-92_Inline
Q55, Q57: IRF9Z34NPBF; TO254P469X1042X1967-3P; Mouser Part Number 942-IRF9Z34NPBF
R115, R118: 1M; R_Axial_DIN0207_L6.3mm_D2.5mm_P2.54mm_Vertical
R116, R119: 100k; R_Axial_DIN0207_L6.3mm_D2.5mm_P2.54mm_Vertical

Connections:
+5V: Q55.3, Q57.3, R116.1, R119.1; also elsewhere on the board
GND: Q54.1 (S), Q56.1 (S), R115.2, R118.2; also elsewhere on the board
IO33: Q57.2; also elsewhere on the board
IO49: Q55.2; also elsewhere on the board
LCDBL: Q54.2 (G), R115.1; also elsewhere on the board
LCDPOWER: Q56.2 (G), R118.1; also elsewhere on the board
unnamed: Q54.3 (D), Q55.1, R116.2
unnamed: Q56.3 (D), Q57.1, R119.2

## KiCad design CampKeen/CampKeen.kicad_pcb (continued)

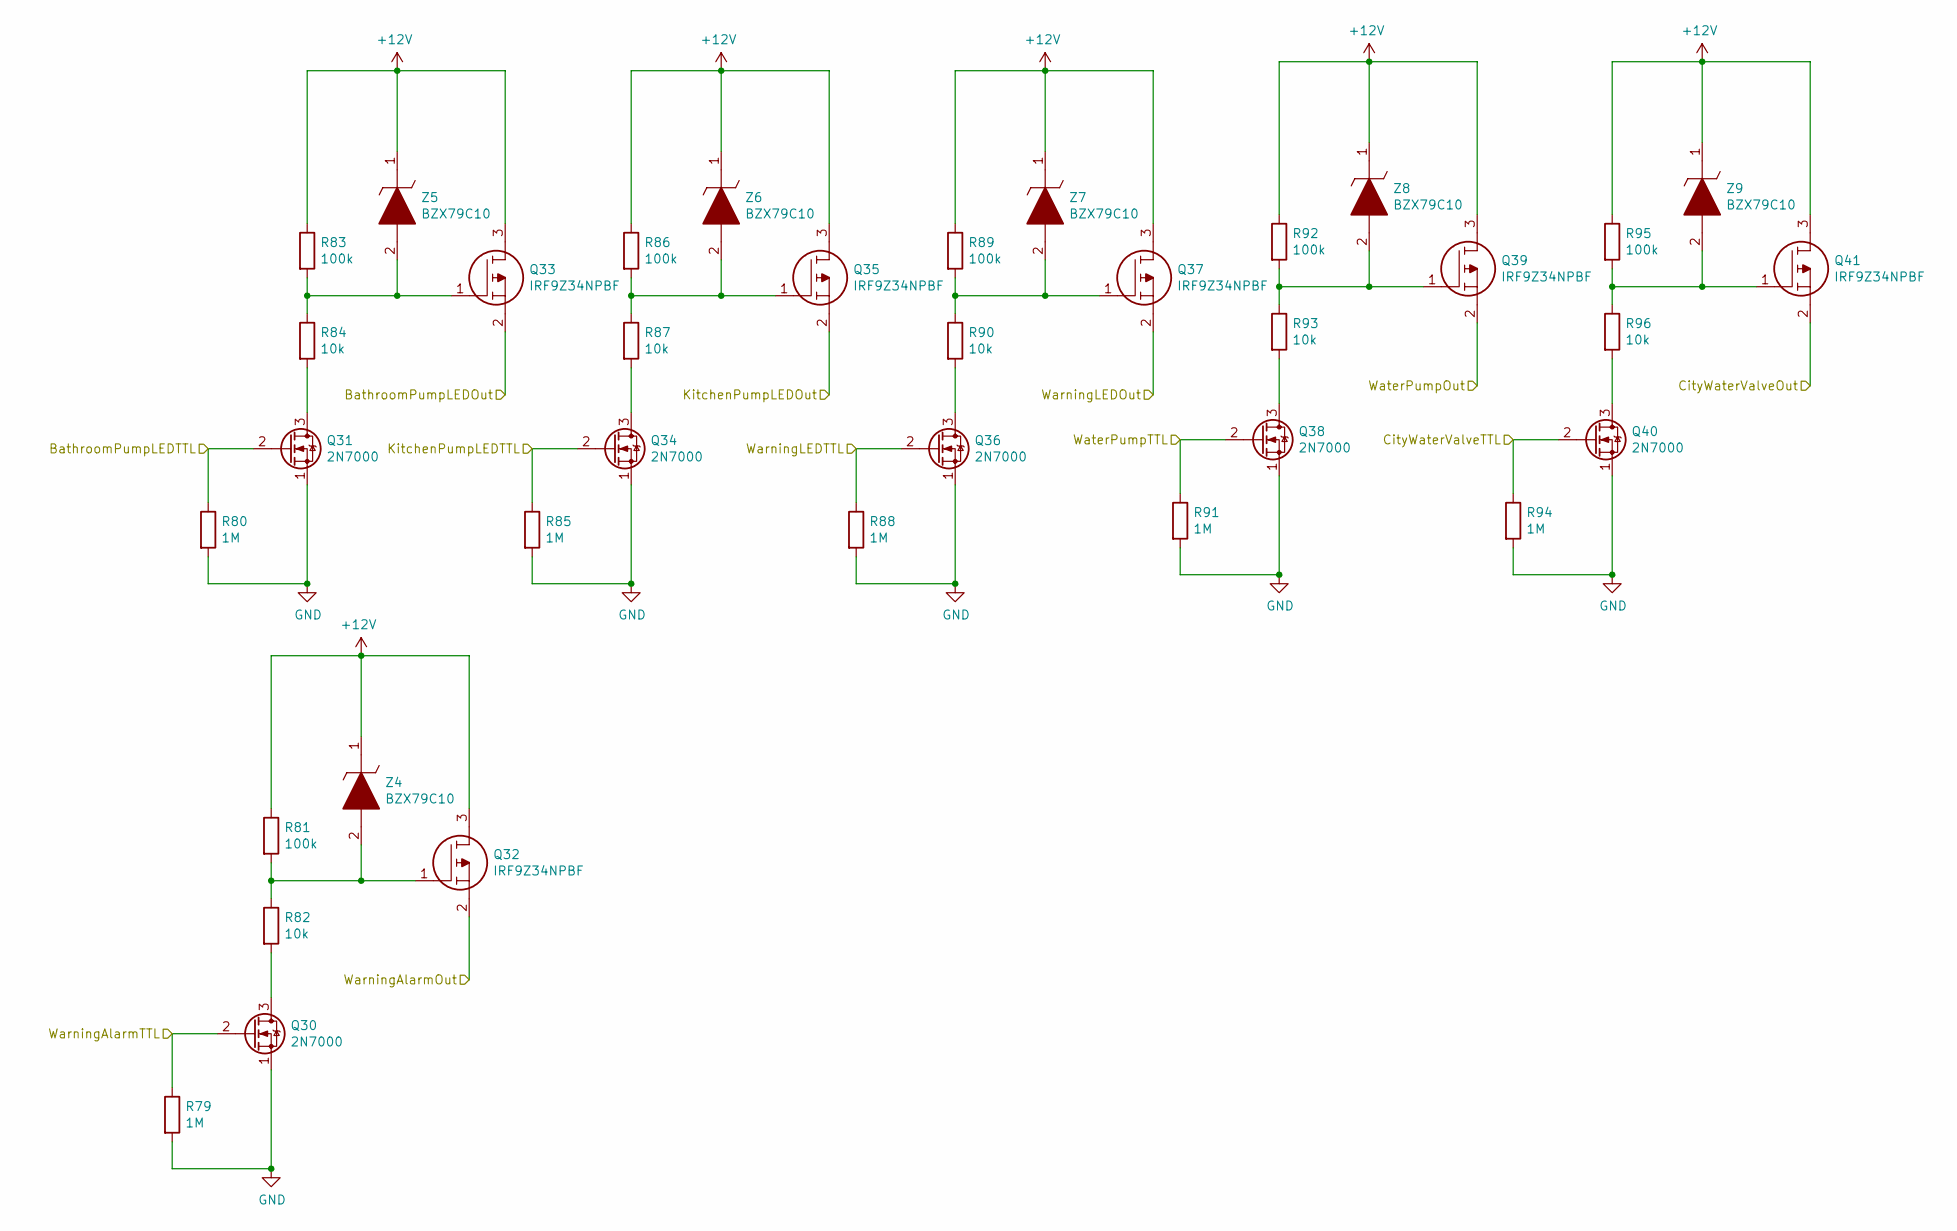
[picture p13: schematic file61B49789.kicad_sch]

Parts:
Q30, Q31, Q34, Q36, Q38, Q40: 2N7000; TO-92_Inline
Q32, Q33, Q35, Q37, Q39, Q41: IRF9Z34NPBF; TO254P469X1042X1967-3P; Mouser Part Number 942-IRF9Z34NPBF
R79, R80, R85, R88, R91, R94: 1M; R_Axial_DIN0207_L6.3mm_D2.5mm_P2.54mm_Vertical
R81, R83, R86, R89, R92, R95: 100k; R_Axial_DIN0207_L6.3mm_D2.5mm_P2.54mm_Vertical
R82, R84, R87, R90, R93, R96: 10k; R_Axial_DIN0207_L6.3mm_D2.5mm_P2.54mm_Vertical
Z4, Z5, Z6, Z7, Z8, Z9: BZX79C10; DIOAD1068W53L380D172; Mouser Part Number 512-BZX79C10

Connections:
+12V: Q32.3, Q33.3, Q35.3, Q37.3, Q39.3, Q41.3, R81.1, R83.1, R86.1, R89.1, R92.1, R95.1, Z4.1, Z5.1, Z6.1, Z7.1, Z8.1, Z9.1; also elsewhere on the board
BRLED: Q31.2 (G), R80.1; also elsewhere on the board
CWV: Q40.2 (G), R94.1; also elsewhere on the board
GND: Q30.1 (S), Q31.1 (S), Q34.1 (S), Q36.1 (S), Q38.1 (S), Q40.1 (S), R79.2, R80.2, R85.2, R88.2, R91.2, R94.2; also elsewhere on the board
IO21: Q39.2; also elsewhere on the board
IO22: Q37.2; also elsewhere on the board
IO25: Q33.2; also elsewhere on the board
IO28: Q35.2; also elsewhere on the board
IO38: Q41.2; also elsewhere on the board
IO211: Q32.2; also elsewhere on the board
KLED: Q34.2 (G), R85.1; also elsewhere on the board
unnamed: Q30.3 (D), R82.2
unnamed: Q31.3 (D), R84.2
unnamed: Q32.1, R81.2, R82.1, Z4.2
unnamed: Q33.1, R83.2, R84.1, Z5.2
unnamed: Q34.3 (D), R87.2
unnamed: Q35.1, R86.2, R87.1, Z6.2
unnamed: Q36.3 (D), R90.2
unnamed: Q37.1, R89.2, R90.1, Z7.2
unnamed: Q38.3 (D), R93.2
unnamed: Q39.1, R92.2, R93.1, Z8.2
unnamed: Q40.3 (D), R96.2
unnamed: Q41.1, R95.2, R96.1, Z9.2
WLED: Q36.2 (G), R88.1; also elsewhere on the board
WP: Q38.2 (G), R91.1; also elsewhere on the board
WSiren: Q30.2 (G), R79.1; also elsewhere on the board

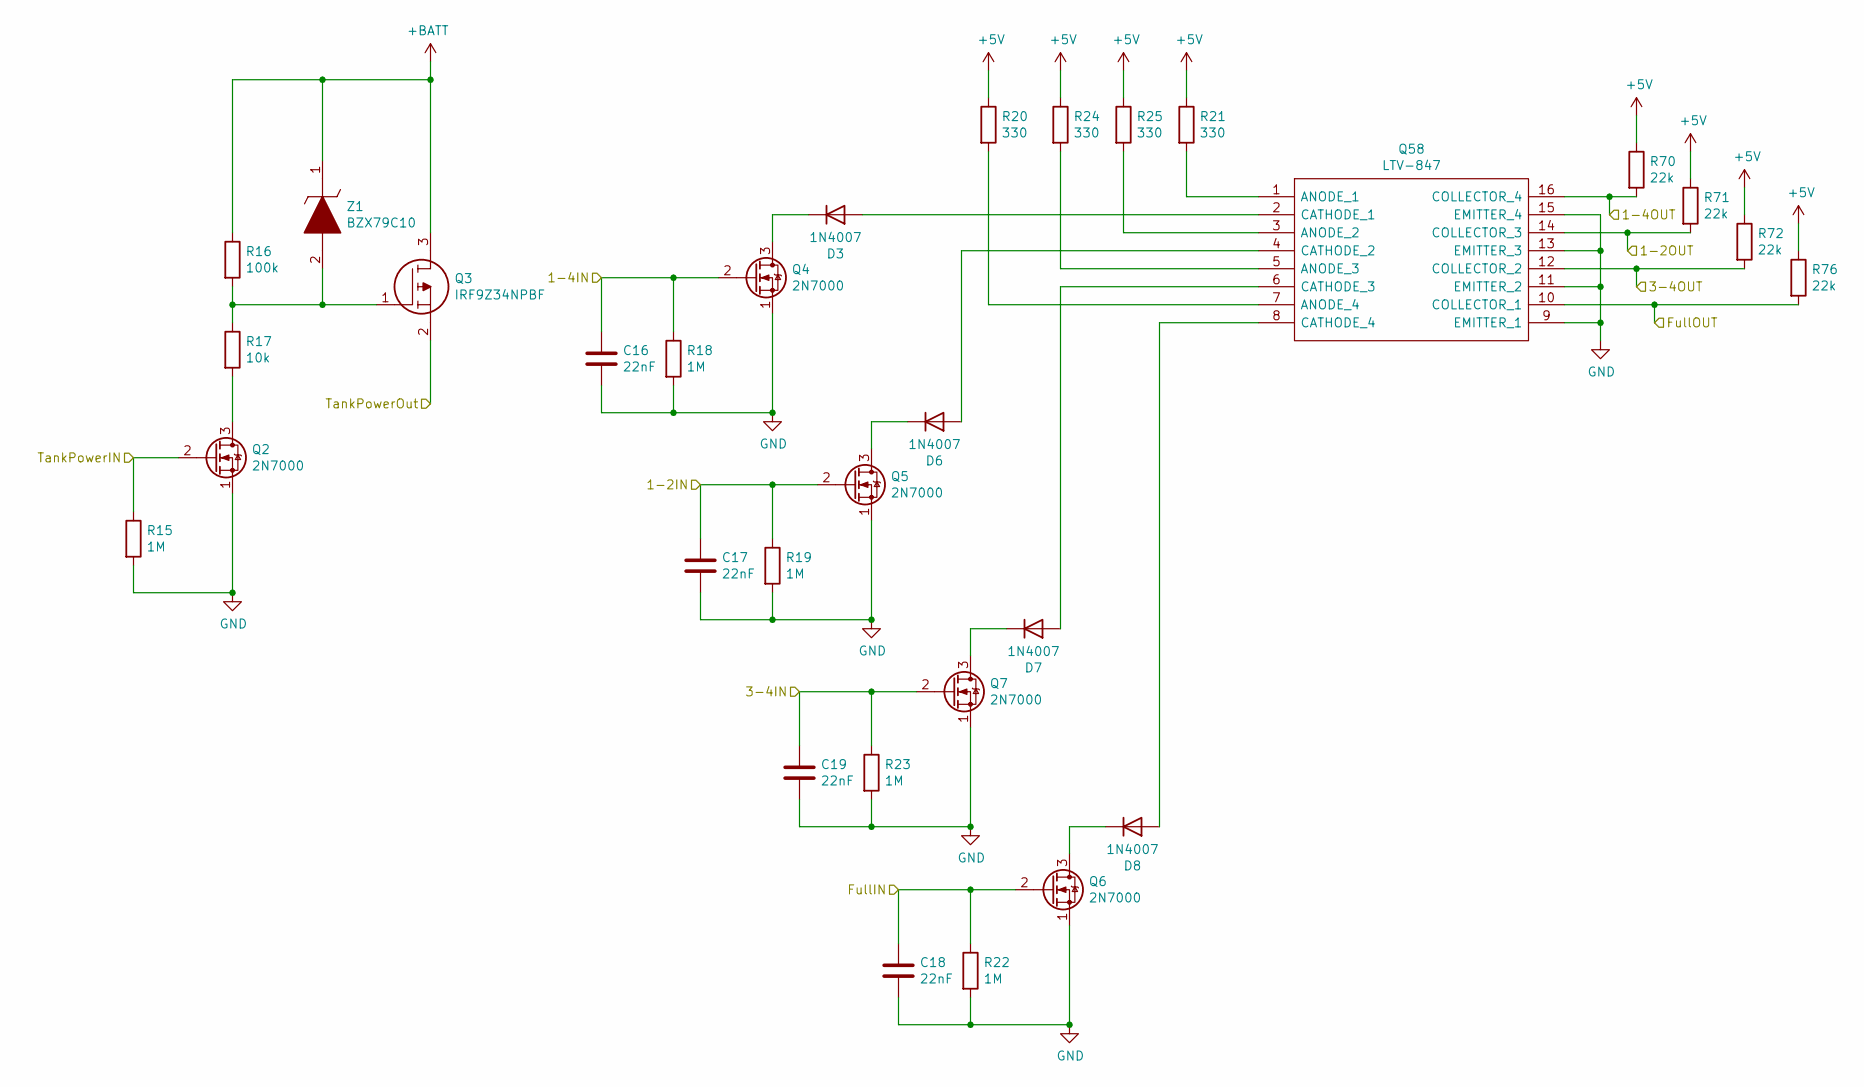
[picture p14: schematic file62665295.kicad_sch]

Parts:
C16, C17, C18, C19: 22nF; C_Disc_D4.7mm_W2.5mm_P5.00mm
D3, D6, D7, D8: 1N4007; D_DO-41_SOD81_P10.16mm_Horizontal
Q2, Q4, Q5, Q6, Q7: 2N7000; TO-92_Inline
Q3: IRF9Z34NPBF; TO254P469X1042X1967-3P; Mouser Part Number 942-IRF9Z34NPBF
Q58: LTV-847; DIP762W60P254L1984H450Q16N; Mouser Part Number 859-LTV-847
R15, R18, R19, R22, R23: 1M; R_Axial_DIN0207_L6.3mm_D2.5mm_P2.54mm_Vertical
R16: 100k; R_Axial_DIN0207_L6.3mm_D2.5mm_P2.54mm_Vertical
R17: 10k; R_Axial_DIN0207_L6.3mm_D2.5mm_P2.54mm_Vertical
R20, R21, R24, R25: 330; R_Axial_DIN0207_L6.3mm_D2.5mm_P2.54mm_Vertical
R70, R71, R72, R76: 22k; R_Axial_DIN0207_L6.3mm_D2.5mm_P2.54mm_Vertical
Z1: BZX79C10; DIOAD1068W53L380D172; Mouser Part Number 512-BZX79C10

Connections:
+5V: R20.1, R21.1, R24.1, R25.1, R70.1, R71.1, R72.1, R76.1; also elsewhere on the board
+BATT: Q3.3, R16.1, Z1.1; also elsewhere on the board
/Tanks/1-2OUT: Q58.14 (COLLECTOR_3), R71.2; also elsewhere on the board
/Tanks/1-4OUT: Q58.16 (COLLECTOR_4), R70.2; also elsewhere on the board
/Tanks/3-4OUT: Q58.12 (COLLECTOR_2), R72.2; also elsewhere on the board
/Tanks/FullOUT: Q58.10 (COLLECTOR_1), R76.2; also elsewhere on the board
GND: C16.2, C17.2, C18.2, C19.2, Q2.1 (S), Q4.1 (S), Q5.1 (S), Q6.1 (S), Q7.1 (S), Q58.9 (EMITTER_1), Q58.11 (EMITTER_2), Q58.13 (EMITTER_3), Q58.15 (EMITTER_4), R15.2, R18.2, R19.2, R22.2, R23.2; also elsewhere on the board
IO12: C16.1, Q4.2 (G), R18.1; also elsewhere on the board
IO15: C17.1, Q5.2 (G), R19.1; also elsewhere on the board
IO17: Q3.2; also elsewhere on the board
IO18: C19.1, Q7.2 (G), R23.1; also elsewhere on the board
IO111: C18.1, Q6.2 (G), R22.1; also elsewhere on the board
unnamed: D3.1 (K), Q4.3 (D)
unnamed: D3.2 (A), Q58.2 (CATHODE_1)
unnamed: D6.1 (K), Q5.3 (D)
unnamed: D6.2 (A), Q58.4 (CATHODE_2)
unnamed: D7.1 (K), Q7.3 (D)
unnamed: D7.2 (A), Q58.6 (CATHODE_3)
unnamed: D8.1 (K), Q6.3 (D)
unnamed: D8.2 (A), Q58.8 (CATHODE_4)
unnamed: Q2.3 (D), R17.2
unnamed: Q3.1, R16.2, R17.1, Z1.2
unnamed: Q58.1 (ANODE_1), R21.2
unnamed: Q58.3 (ANODE_2), R25.2
unnamed: Q58.5 (ANODE_3), R24.2
unnamed: Q58.7 (ANODE_4), R20.2
STV: Q2.2 (G), R15.1; also elsewhere on the board

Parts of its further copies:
C20, C21, C22, C23: 22nF; C_Disc_D4.7mm_W2.5mm_P5.00mm
D9, D10, D11, D12: 1N4007; D_DO-41_SOD81_P10.16mm_Horizontal
Q10, Q12, Q13, Q14, Q15: 2N7000; TO-92_Inline
Q11: IRF9Z34NPBF; TO254P469X1042X1967-3P; Mouser Part Number 942-IRF9Z34NPBF
Q59: LTV-847; DIP762W60P254L1984H450Q16N; Mouser Part Number 859-LTV-847
R40, R43, R44, R47, R48: 1M; R_Axial_DIN0207_L6.3mm_D2.5mm_P2.54mm_Vertical
R41: 100k; R_Axial_DIN0207_L6.3mm_D2.5mm_P2.54mm_Vertical
R42: 10k; R_Axial_DIN0207_L6.3mm_D2.5mm_P2.54mm_Vertical
R45, R46, R49, R50: 330; R_Axial_DIN0207_L6.3mm_D2.5mm_P2.54mm_Vertical
R77, R78, R122, R123: 22k; R_Axial_DIN0207_L6.3mm_D2.5mm_P2.54mm_Vertical
Z3: BZX79C10; DIOAD1068W53L380D172; Mouser Part Number 512-BZX79C10

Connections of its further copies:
+5V: R45.1, R46.1, R49.1, R50.1, R77.1, R78.1, R122.1, R123.1; also elsewhere on the board
+BATT: Q11.3, R41.1, Z3.1; also elsewhere on the board
/sheet6479D10C/1-2OUT: Q59.14 (COLLECTOR_3), R78.2; also elsewhere on the board
/sheet6479D10C/1-4OUT: Q59.16 (COLLECTOR_4), R77.2; also elsewhere on the board
/sheet6479D10C/3-4OUT: Q59.12 (COLLECTOR_2), R122.2; also elsewhere on the board
/sheet6479D10C/FullOUT: Q59.10 (COLLECTOR_1), R123.2; also elsewhere on the board
GND: C20.2, C21.2, C22.2, C23.2, Q10.1 (S), Q12.1 (S), Q13.1 (S), Q14.1 (S), Q15.1 (S), Q59.9 (EMITTER_1), Q59.11 (EMITTER_2), Q59.13 (EMITTER_3), Q59.15 (EMITTER_4), R40.2, R43.2, R44.2, R47.2, R48.2; also elsewhere on the board
GreyV: Q10.2 (G), R40.1; also elsewhere on the board
IO13: C20.1, Q12.2 (G), R43.1; also elsewhere on the board
IO16: C21.1, Q13.2 (G), R44.1; also elsewhere on the board
IO19: C23.1, Q15.2 (G), R48.1; also elsewhere on the board
IO110: Q11.2; also elsewhere on the board
IO112: C22.1, Q14.2 (G), R47.1; also elsewhere on the board
unnamed: D9.1 (K), Q12.3 (D)
unnamed: D9.2 (A), Q59.2 (CATHODE_1)
unnamed: D10.1 (K), Q13.3 (D)
unnamed: D10.2 (A), Q59.4 (CATHODE_2)
unnamed: D11.1 (K), Q15.3 (D)
unnamed: D11.2 (A), Q59.6 (CATHODE_3)
unnamed: D12.1 (K), Q14.3 (D)
unnamed: D12.2 (A), Q59.8 (CATHODE_4)
unnamed: Q10.3 (D), R42.2
unnamed: Q11.1, R41.2, R42.1, Z3.2
unnamed: Q59.1 (ANODE_1), R46.2
unnamed: Q59.3 (ANODE_2), R50.2
unnamed: Q59.5 (ANODE_3), R49.2
unnamed: Q59.7 (ANODE_4), R45.2

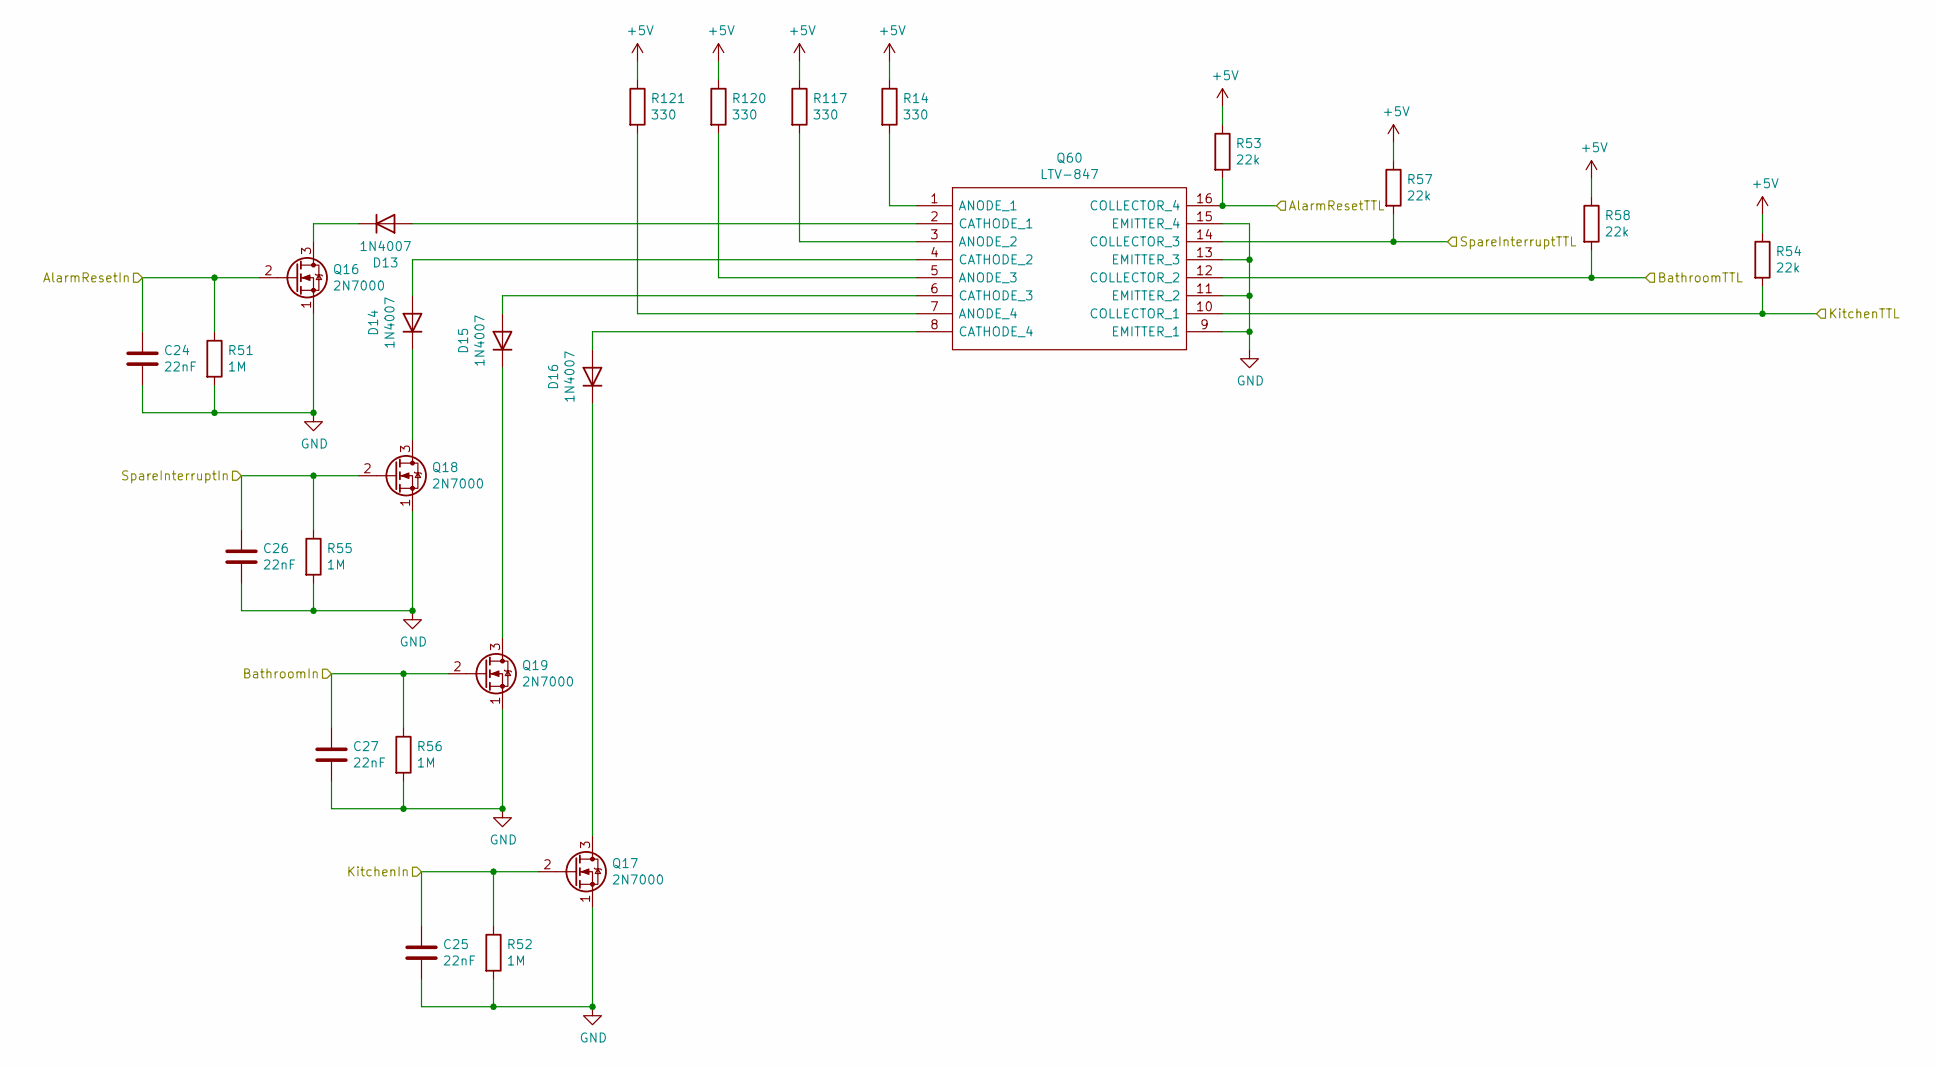
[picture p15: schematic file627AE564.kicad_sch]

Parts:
C24, C25, C26, C27: 22nF; C_Disc_D4.7mm_W2.5mm_P5.00mm
D13, D14, D15, D16: 1N4007; D_DO-41_SOD81_P10.16mm_Horizontal
Q16, Q17, Q18, Q19: 2N7000; TO-92_Inline
Q60: LTV-847; DIP762W60P254L1984H450Q16N; Mouser Part Number 859-LTV-847
R14, R117, R120, R121: 330; R_Axial_DIN0207_L6.3mm_D2.5mm_P2.54mm_Vertical
R51, R52, R55, R56: 1M; R_Axial_DIN0207_L6.3mm_D2.5mm_P2.54mm_Vertical
R53, R54, R57, R58: 22k; R_Axial_DIN0207_L6.3mm_D2.5mm_P2.54mm_Vertical

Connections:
+5V: R14.1, R53.1, R54.1, R57.1, R58.1, R117.1, R120.1, R121.1; also elsewhere on the board
/Inputs With Interrupts/AlarmResetTTL: Q60.16 (COLLECTOR_4), R53.2; also elsewhere on the board
/Inputs With Interrupts/BathroomTTL: Q60.12 (COLLECTOR_2), R58.2; also elsewhere on the board
/Inputs With Interrupts/KitchenTTL: Q60.10 (COLLECTOR_1), R54.2; also elsewhere on the board
/Inputs With Interrupts/SpareInterruptTTL: Q60.14 (COLLECTOR_3), R57.2; also elsewhere on the board
GND: C24.2, C25.2, C26.2, C27.2, Q16.1 (S), Q17.1 (S), Q18.1 (S), Q19.1 (S), Q60.9 (EMITTER_1), Q60.11 (EMITTER_2), Q60.13 (EMITTER_3), Q60.15 (EMITTER_4), R51.2, R52.2, R55.2, R56.2; also elsewhere on the board
IO23: C26.1, Q18.2 (G), R55.1; also elsewhere on the board
IO26: C27.1, Q19.2 (G), R56.1; also elsewhere on the board
IO29: C25.1, Q17.2 (G), R52.1; also elsewhere on the board
IO212: C24.1, Q16.2 (G), R51.1; also elsewhere on the board
unnamed: D13.1 (K), Q16.3 (D)
unnamed: D13.2 (A), Q60.2 (CATHODE_1)
unnamed: D14.1 (K), Q18.3 (D)
unnamed: D14.2 (A), Q60.4 (CATHODE_2)
unnamed: D15.1 (K), Q19.3 (D)
unnamed: D15.2 (A), Q60.6 (CATHODE_3)
unnamed: D16.1 (K), Q17.3 (D)
unnamed: D16.2 (A), Q60.8 (CATHODE_4)
unnamed: Q60.1 (ANODE_1), R14.2
unnamed: Q60.3 (ANODE_2), R117.2
unnamed: Q60.5 (ANODE_3), R120.2
unnamed: Q60.7 (ANODE_4), R121.2

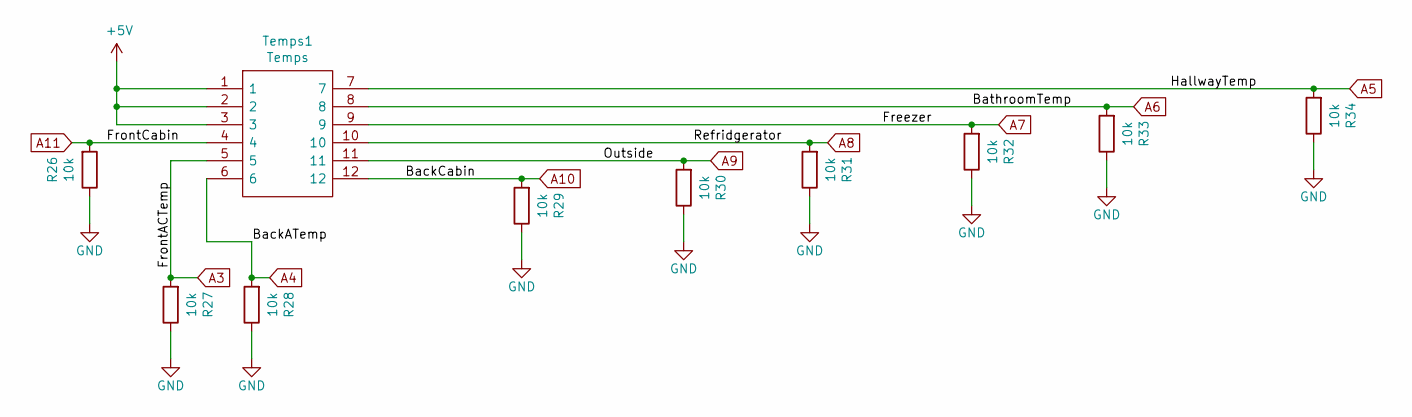
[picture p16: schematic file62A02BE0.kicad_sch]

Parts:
R26, R27, R28, R29, R30, R31, R32, R33, R34: 10k; R_Axial_DIN0207_L6.3mm_D2.5mm_P2.54mm_Vertical
Temps1: Temps; 1727751; Mouser Part Number 651-1727751

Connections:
+5V: Temps1.1, Temps1.2, Temps1.3; also elsewhere on the board
A3: R27.2, Temps1.5; also elsewhere on the board
A4: R28.2, Temps1.6; also elsewhere on the board
A5: R34.2, Temps1.7; also elsewhere on the board
A6: R33.2, Temps1.8; also elsewhere on the board
A7: R32.2, Temps1.9; also elsewhere on the board
A8: R31.2, Temps1.10; also elsewhere on the board
A9: R30.2, Temps1.11; also elsewhere on the board
A10: R29.2, Temps1.12; also elsewhere on the board
A11: R26.2, Temps1.4; also elsewhere on the board
GND: R26.1, R27.1, R28.1, R29.1, R30.1, R31.1, R32.1, R33.1, R34.1; also elsewhere on the board

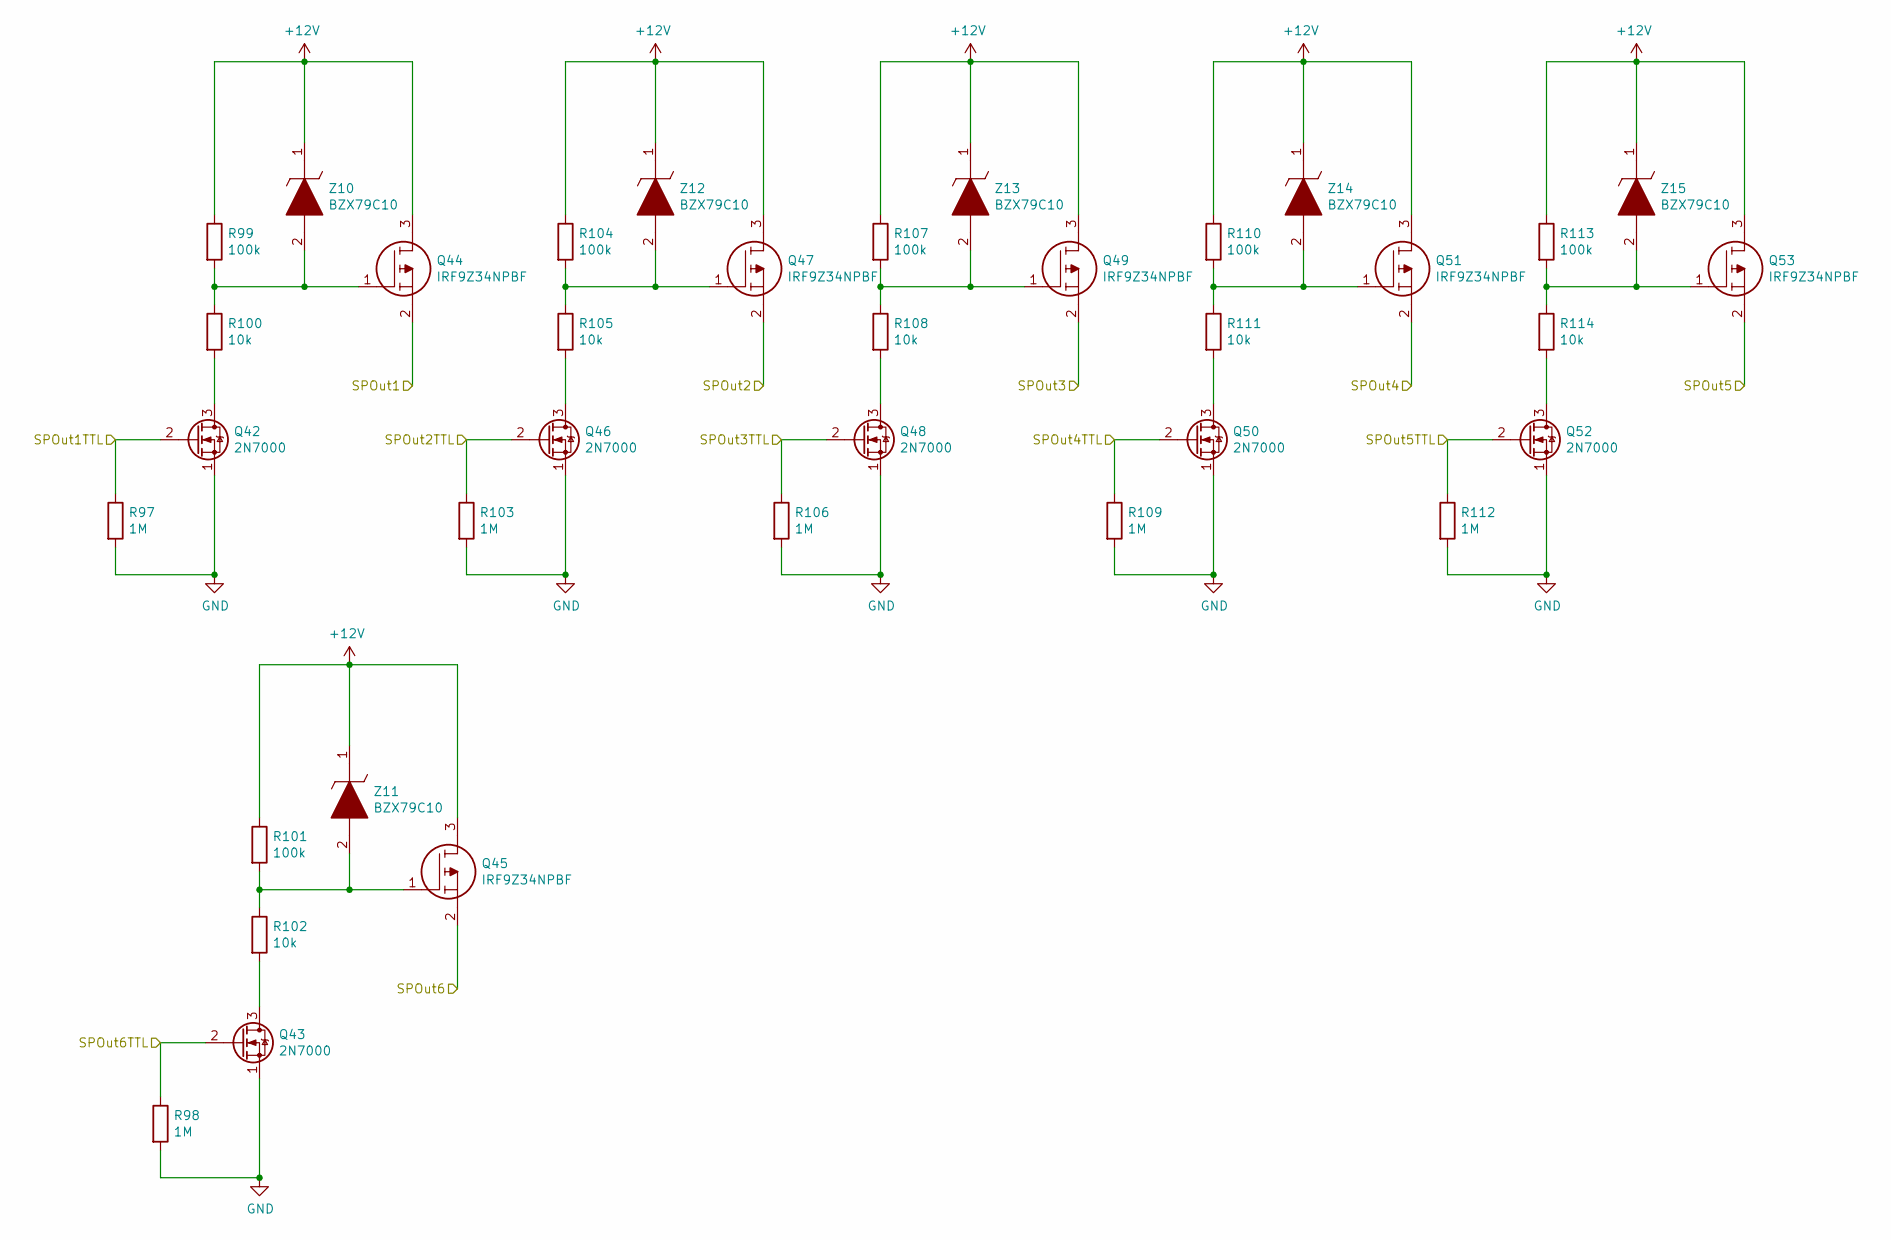
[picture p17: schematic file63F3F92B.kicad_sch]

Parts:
Q42, Q43, Q46, Q48, Q50, Q52: 2N7000; TO-92_Inline
Q44, Q45, Q47, Q49, Q51, Q53: IRF9Z34NPBF; TO254P469X1042X1967-3P; Mouser Part Number 942-IRF9Z34NPBF
R97, R98, R103, R106, R109, R112: 1M; R_Axial_DIN0207_L6.3mm_D2.5mm_P2.54mm_Vertical
R99, R101, R104, R107, R110, R113: 100k; R_Axial_DIN0207_L6.3mm_D2.5mm_P2.54mm_Vertical
R100, R102, R105, R108, R111, R114: 10k; R_Axial_DIN0207_L6.3mm_D2.5mm_P2.54mm_Vertical
Z10, Z11, Z12, Z13, Z14, Z15: BZX79C10; DIOAD1068W53L380D172; Mouser Part Number 512-BZX79C10

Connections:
+12V: Q44.3, Q45.3, Q47.3, Q49.3, Q51.3, Q53.3, R99.1, R101.1, R104.1, R107.1, R110.1, R113.1, Z10.1, Z11.1, Z12.1, Z13.1, Z14.1, Z15.1; also elsewhere on the board
GND: Q42.1 (S), Q43.1 (S), Q46.1 (S), Q48.1 (S), Q50.1 (S), Q52.1 (S), R97.2, R98.2, R103.2, R106.2, R109.2, R112.2; also elsewhere on the board
IO32: Q53.2; also elsewhere on the board
IO35: Q45.2; also elsewhere on the board
IO42: Q44.2; also elsewhere on the board
IO45: Q47.2; also elsewhere on the board
IO48: Q49.2; also elsewhere on the board
IO411: Q51.2; also elsewhere on the board
unnamed: Q42.3 (D), R100.2
unnamed: Q43.3 (D), R102.2
unnamed: Q44.1, R99.2, R100.1, Z10.2
unnamed: Q45.1, R101.2, R102.1, Z11.2
unnamed: Q46.3 (D), R105.2
unnamed: Q47.1, R104.2, R105.1, Z12.2
unnamed: Q48.3 (D), R108.2
unnamed: Q49.1, R107.2, R108.1, Z13.2
unnamed: Q50.3 (D), R111.2
unnamed: Q51.1, R110.2, R111.1, Z14.2
unnamed: Q52.3 (D), R114.2
unnamed: Q53.1, R113.2, R114.1, Z15.2
SO1: Q42.2 (G), R97.1; also elsewhere on the board
SO2: Q46.2 (G), R103.1; also elsewhere on the board
SO3: Q48.2 (G), R106.1; also elsewhere on the board
SO4: Q50.2 (G), R109.1; also elsewhere on the board
SO5: Q52.2 (G), R112.1; also elsewhere on the board
SO6: Q43.2 (G), R98.1; also elsewhere on the board

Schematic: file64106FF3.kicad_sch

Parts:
LPWater1: LPGVS; BK_HTC-15M; Mouser Part Number 504-HTC-15M
Q8: 2N7000; TO-92_Inline
Q9: IRF9Z34NPBF; TO254P469X1042X1967-3P; Mouser Part Number 942-IRF9Z34NPBF
R35: 1M; R_Axial_DIN0207_L6.3mm_D2.5mm_P2.54mm_Vertical
R36: 100k; R_Axial_DIN0207_L6.3mm_D2.5mm_P2.54mm_Vertical
R37: 10k; R_Axial_DIN0207_L6.3mm_D2.5mm_P2.54mm_Vertical
R38, R39: 47; R_Axial_DIN0207_L6.3mm_D2.5mm_P2.54mm_Vertical
Z2: BZX79C10; DIOAD1068W53L380D172; Mouser Part Number 512-BZX79C10

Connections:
+5V: LPWater1.2; also elsewhere on the board
A1: R38.1; also elsewhere on the board
A2: R39.2; also elsewhere on the board
GND: Q8.1 (S), R35.2, R39.1; also elsewhere on the board
IO14: Q9.2, R38.2; also elsewhere on the board
unnamed: LPWater1.1, Q9.3, R36.1, Z2.1
unnamed: Q8.3 (D), R37.2
unnamed: Q9.1, R36.2, R37.1, Z2.2
RTankPOWER: Q8.2 (G), R35.1; also elsewhere on the board


Board: 4 copper layers, 193.7 x 142.2 mm, 326 parts (0 on the bottom side), 266 nets.

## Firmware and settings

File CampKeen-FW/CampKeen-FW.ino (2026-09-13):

#include <Wire.h>
#include <Adafruit_MAX31865.h>
#include <SPI.h>
#include <RTClib.h>
#include <EEPROM.h>
#include <ATM90E32.h>


//-----------------------------------------------------------
// Serial Communication, UI
//-----------------------------------------------------------
#define USBSerial Serial
#define RS232 Serial2
char* AcceptedCommands[] = {"UNITS?", "DEVICE?", "WATERSOURCE?", "WATERLEVEL?", "LPG?", "SEWAGE?", "GREY?",
                            "ENERGY?", "BATTERY?", "RTCBATTERY?", "GENERATOR?", "TEMPS?", "UNITTEMP?", "WATERPUMPSENSE?", "WARNING?",
                            "WATER?", "STREAMING?", "ACENMON?", "ALLDATA?", "UPDATEALL", "RESETWARNINGS", "RESETALLALARMS",
                            "TIME?", "ACVOLTAGEGAIN?", "ACFREQ?", "ACPGAGAIN?", "ACLEGS?", "ACCT1GAIN?", "ACCT2GAIN?", "REBOOT",
                            "RESET", "BATHROOMWATERDURATION?", "STREAMINGONBOOT?", "ACENMONONBOOT?", "WATERPUMPSENSEONBOOT?", "STATUS?", "PORT?",
                            "ALARM?", "WATERSOURCEOVERRIDE?", "WATERSOURCEOVERRIDEONBOOT?", "TRAVEL?", "KITCHENWATERDURATION?", "TANKALARMOVERRIDE?",
                            "WARNINGINDICATOR?"
                           };
char* ParameterCommands[] = {"SETUNITS", "SETWATERPUMPSENSE", "WATER", "SETSTREAMINGDATA", "SETTIME", "SETACENMON", "SETACFREQ",
                             "SETACPGAGAIN", "SETACVOLTAGEGAIN", "SETACLEGS", "SETACCT1GAIN", "SETACCT2GAIN", "SETBATHROOMWATERDURATION",
                             "SETSTREAMINGONBOOT", "SETACENMONONBOOT", "SETWATERPUMPSENSEONBOOT", "SETWATERSOURCEOVERRIDE",
                             "SETWATERSOURCE", "SETWATERSOURCEOVERRIDEONBOOT", "SETTRAVEL", "SETKITCHENWATERDURATION", "SETTANKALARMOVERRIDE",
                             "SETWARNINGINDICATOR"
                            };
String inputString, inputStringRS232 = "";         // a String to hold incoming data from ports
bool stringComplete, stringCompleteRS232 = false;     // whether the string is complete for each respective port
//-----------------------------------------------------------
// ATM90E32 energy monitor
ATM90E32 eic{}; // Energy Monitor Object
unsigned short LineFreq, PGAGain, VoltageGain, CurrentGainCT1, CurrentGainCT2;
int NumberOfACLegs;
//-----------------------------------------------------------
//-----------------------------------------------------------
// System Level
RTC_DS3231 rtc;
const String DeviceName = "CampKeen";
const String FWVersion = "1.6.0";
const float ConversionFactor = 5.0 / 1023;
bool WarningActive, TankAlarmOverRide, AlarmActive = false;
bool WarningIndicator = true;
int TotalWarnings = 8;
int ArrayOfWarnings[] = {};
int BathroomWaterDurationInSeconds, KitchenWaterDurationInSeconds, WhoTurnedOnTheWater;
long BathroomWaterTimer, ShitterTankTimer, GreyTankTimer, WATERLPGtimer, FiveMinTimer, DisplayTimer, NTCTimer,
     EnergyTimer, OutputTimer, HoldingTankTimer, WarningBlinkTimer, KitchenWaterTimer, HoldingSewageTankPost, HoldingGreyTankPost;
bool WaterSourseSelection, WaterOn, EnableACEnergyMonitoring,
     UseWaterPumpSense, StreamingDataUSB, StreamingDataRS232, WaterSourceOverRide, Travel, LastSourceForCheck = false;
bool ButtonsReleased = true;
char Units;
String TempUnits, PressureUnits;
//-----------------------------------------------------------
/*
   All the Stored Values and Times to have states
   that can be recalled if streaming is turned off
*/
//Water and LPG
String LastTimeWaterSource, LastTimeWaterLevel = "";
String LastWaterLevel = "Empty";
int LastLPGLevel = 0;
//Holding tanks
String LastSewageLevel, LastGreyWater = "Empty";
String LastTimeSewageLevel, LastTimeGreyWater = "";
//Battery Monitoring
float LastDCVoltage, LastRTCVoltage = 0.0;
String LastTimeDCVoltage, LastTimeRTCVoltage = "";
//NTC Temps
String LastTimeNTCTemp = "";
float LastFrontACTemp, LastBackACTemp, LastOutsideTemp, LastBackCabinTemp, LastHallwayTemp, LastFreezerTemp, LastFridgeTemp,
      LastBathroomTemp, LastFrontCabinTemp = 0.0;
//Generator
String LastTimeGenSensors = "";
float LastGenEnclosureTemp, LastGenHeadRightTemp, LastGenHeadLeftTemp, LastGenFuel = 0.0;
//AC&Energy Monitoring
String LastTimeACVoltage = "";
float LastACVoltage, LastACCurrent, LastPowerFactor, LastFreq, LastACWatts, LastACReactive, LastACApparent, LastACFundimental,
      LastACHarmonic, LastATM90E32Temp, LastACRealPower = 0.0;
//RTC TEMP
float LastRTCTemp = 0.0;
String LastTimeRTCTemp = "";
//-----------------------------------------------------------
//-----------------------------------------------------------
//Generator, Energy Monitoring, and Voltage
#define GenFuelPressure A12
#define RTDGenHeadRCS 45
#define RTDGenHeadLCS 47
#define RTDGenEnclosure 49
#define RREF      430.0
#define RNOMINAL  100.0
Adafruit_MAX31865 GenHeadR = Adafruit_MAX31865(RTDGenHeadRCS);
Adafruit_MAX31865 GenHeadL = Adafruit_MAX31865(RTDGenHeadLCS);
Adafruit_MAX31865 GenEnclosure = Adafruit_MAX31865(RTDGenEnclosure);
#define Camper12VoltSensor A0
#define RTCBattery A14
#define EnergyMonitorCS 24
#define EnergyMonTransformerEnable 15
//-----------------------------------------------------------
//-----------------------------------------------------------
//NTC Temperature Sensors
#define FrontACTemp A3
#define BackACTemp A4
#define HallwayTemp A5
#define BathroomTemp A6
#define Freezer A7
#define Refridgerator A8
#define Outside A9
#define BackCabin A10
#define FrontCabin A11
//-----------------------------------------------------------
//-----------------------------------------------------------
//Alarm
#define LEDBacklightOut 8
#define AlarmOut 4
#define WarningLED 5
#define AlarmReset 3
//-----------------------------------------------------------
//-----------------------------------------------------------
// Spare Inputs Outputs and Analog
#define SpareInput1 35
//#define SpareInput2 33
#define SpareInput3 31
#define SpareInput4 29
#define SpareInput5 27
#define SpareInput6 25

#define SpareOutput1 12
#define SpareOutput2 11
#define SpareOutput3 10
#define SpareOutput4 9
#define SpareOutput5 14

#define AUX1 13
#define AUX2 15
//-----------------------------------------------------------
//-----------------------------------------------------------
//Water Control / Tanks and LPG Tank
#define LPGSensor A1
#define WaterTankSensor A2
#define TankPowerRelay 22
#define WaterSourceSelectionInput 37
#define WaterPumpSense 43
#define KitchWaterButton 18
#define BathroomWaterButton 19
#define CityWaterValve 28
#define KitchenWaterButtonLED 6
#define BathroomWaterButtonLED 7
#define WaterPumpOut 26
//-----------------------------------------------------------
//-----------------------------------------------------------
// Holding Tank
bool ShittersGettinFull, GreyGettinFull, HoldingTankAlarm = false;
//SewageTankLevelPins
#define S14 48
#define S12 46
#define S34 44
#define S44 42
#define SewagePower 30
//GreyTankLevelPins
#define G14 40
#define G12 38
#define G34 36
#define G44 34
#define GreyWaterPower 32
//-----------------------------------------------------------
void setup() {
  rtc.begin();
  RS232.begin(115200);
  USBSerial.begin(115200);
  inputString.reserve(200);
  inputStringRS232.reserve(200);

  pinMode(AlarmReset, INPUT);
  pinMode(WaterSourceSelectionInput, INPUT);
  pinMode(WaterPumpSense, INPUT);
  pinMode(KitchWaterButton, INPUT);
  pinMode(BathroomWaterButton, INPUT);

  pinMode(LEDBacklightOut, OUTPUT);
  pinMode(TankPowerRelay, OUTPUT);
  pinMode(WaterPumpOut, OUTPUT);
  pinMode(AlarmOut, OUTPUT);
  pinMode(WarningLED, OUTPUT);
  pinMode(CityWaterValve, OUTPUT);
  pinMode(KitchenWaterButtonLED, OUTPUT);
  pinMode(BathroomWaterButtonLED, OUTPUT);

  //Sewage Tank
  pinMode(SewagePower, OUTPUT);
  pinMode(S14, INPUT);
  pinMode(S12, INPUT);
  pinMode(S34, INPUT);
  pinMode(S44, INPUT);

  //Grey Water
  pinMode(GreyWaterPower, OUTPUT);
  pinMode(G14, INPUT);
  pinMode(G12, INPUT);
  pinMode(G34, INPUT);
  pinMode(G44, INPUT);

  //Generator
  pinMode(RTDGenHeadRCS, OUTPUT);
  pinMode(RTDGenHeadLCS, OUTPUT);
  pinMode(RTDGenEnclosure, OUTPUT);
  /*
      Please Reference Adafruit_MAX31865
      docs for setup of these boards if
      you are going to use 4 or 2 wire
  */
  GenHeadR.begin(MAX31865_3WIRE);
  GenHeadL.begin(MAX31865_3WIRE);
  GenEnclosure.begin(MAX31865_3WIRE);

  //Energy
  //Load from EEProm
  EnableACEnergyMonitoring = GetFromEEPROMACENMONOnBoot();
  LineFreq = GetFromEEPROMACFREQ();
  PGAGain = GetFromEEPROMACPGAGain();
  VoltageGain = GetFromEEPROMACVOLTAGEGAIN();
  CurrentGainCT1 = GetFromEEPROMACCurrentGainCT1();
  CurrentGainCT2 = GetFromEEPROMACCurrentGainCT2();
  NumberOfACLegs = GetFromEEPROMACLegs();

  //Load Streaming Setting from EEProm
  StreamingDataUSB = GetFromEEPROMStreamOnBootUSB();
  StreamingDataRS232 = GetFromEEPROMStreamOnBootRS232();

  //load system settings from EEProm
  BathroomWaterDurationInSeconds = GetFromEEPROMBathroomWaterDuration();
  KitchenWaterDurationInSeconds = GetFromEEPROMKitchenWaterDuration();
  UseWaterPumpSense = GetFromEEPROMWaterPumpSenseOnBoot();
  WaterSourceOverRide = GetFromEEPROMWaterSourceOverRideOnBoot();

  pinMode(EnergyMonTransformerEnable, OUTPUT);
  pinMode(EnergyMonitorCS, OUTPUT);
  EnablingPowerToTransformerForEnergyMonitoring();

  //Set Warning Array up with -1 for being cleared.
  ResetWarnings();

  //Set up displays and output on the Serial Port
  BroadCast("Starting " + DeviceName);
  BroadCast("FW: " + FWVersion);
  Units = GetFromEEPROMUnits();
  SetUnitsForOutput();
  BroadCast("Units: " + String(Units));
  //Run through the sensors and get values for everything
  ForceCompleteUpdateOfAllStates();
  BroadCast("System Initialized and values populated:" + GetCurrentTime());
}

void loop() {
  MainApplication();
  /*
    Handle the Incoming commands from the Serial Ports
    after all the other operations have been done
  */
  if (stringComplete) {
    inputString = PainlessInstructionSet(inputString, 0);
    stringComplete = false;
  }

  serialRS232();
  if (stringCompleteRS232) {
    stringCompleteRS232 = PainlessInstructionSet(inputStringRS232, 1);
    stringCompleteRS232 = false;
  }
}


void MainApplication() {
  /*
     All the basic functions that need to be handled
     everytime the loop comes back around
  */
  WaterControl();
  if (Travel == false) {
    HoldingTankMonitoring();
  }
  /*
     Handle reseting the warnings and alarms
     If reset High warnings/alarms are
     flushed and silenced until brought low
  */
  if (digitalRead(AlarmReset) == HIGH) {
    ResetAllAlarmsAndWarnings();
  }
  else {
    Warning();
  }

  /*
     Read Sensors at 3 Second intervals
     Sensors to be read:
     NTC Temp sensors
     Generator Fuel Pressure & Temp sensors
  */
  if (abs(millis() - NTCTimer) > 3000) {
    ReadOtherTempSensors();
    GeneratorSensors();
    NTCTimer = millis();
    if (StreamingDataUSB == true) {
      GetNTCTemps(0);
      GetGenStatus(0);
    }
    if (StreamingDataRS232 == true) {
      GetNTCTemps(1);
      GetGenStatus(1);
    }
  }

  /*
     Read Energy Montioring at 10 Second Intervals if
     enabled and mmodule is installed
  */
  if ((abs(millis() - EnergyTimer) > 10000) && EnableACEnergyMonitoring == true) {
    EnergyMetering();
    EnergyTimer = millis();
    if (StreamingDataUSB == true) {
      GetEnergyStatus(0);
    }
    if (StreamingDataRS232 == true) {
      GetEnergyStatus(1);
    }
  }

  /*
     Read Sensors at 30 Min Intervals
     Sensors to be read:
     Water Tank Level
     LPG Tank Level
  */
  if (Travel == false) {
    if (abs(millis() - WATERLPGtimer) > 1800000) {
      ReadWaterAndLPG();
      WATERLPGtimer = millis();
      if (StreamingDataUSB == true) {
        GetWaterLevel(0);
        GetLPGLevel(0);
      }
      if (StreamingDataRS232 == true) {
        GetWaterLevel(1);
        GetLPGLevel(1);
      }
    }
  }

  /*
      Read Sensors at 5 Min Intervals
      Sensors to be read:
      Camper Battery Voltage
      RTC Battery Voltage
  */
  if (abs(millis() - FiveMinTimer) > 300000) {
    ReadBatteryVoltages();
    FiveMinTimer = millis();
    if (StreamingDataUSB == true) {
      GetDCBatteryVoltage(0);
      GetRTCBatteryVotlage(0);
    }
    if (StreamingDataRS232 == true) {
      GetDCBatteryVoltage(1);
      GetRTCBatteryVotlage(1);
    }
  }
}
//------------------------------------------------------------------
//Water Control
//------------------------------------------------------------------
void WaterControl() {
  if (WaterSourceOverRide == false) {
    //Read Current Water Source Selection
    LastSourceForCheck = WaterSourseSelection;
    if (digitalRead(WaterSourceSelectionInput) == HIGH) {
      WaterSourseSelection = true;//city water
    }
    else {
      WaterSourseSelection = false; //Tank
    }
  }

  if (WaterOn == true && (LastSourceForCheck != WaterSourseSelection)) {
    TurnOffWater();
    delay(1000);
    TurnOnWater(true);
    if (StreamingDataUSB == true) {
      GetWaterSource(0);
    }
    if (StreamingDataRS232 == true) {
      GetWaterSource(1);
    }
  }

  //if the water is on and the timer says it's more than the set WaterDuration then turn it off.
  bool SkipTurningOnIfIjustTurnedItOff = false;
  long Delta, WaterDurationInSeconds = 0;
  if (WhoTurnedOnTheWater == 1 || WhoTurnedOnTheWater == 0) {
    Delta = abs(millis() - BathroomWaterTimer) / 1000;
    WaterDurationInSeconds = BathroomWaterDurationInSeconds;
  }
  if (WhoTurnedOnTheWater == 2) {
    Delta = abs(millis() - KitchenWaterTimer) / 1000;
    WaterDurationInSeconds = KitchenWaterDurationInSeconds;
  }

  if (WaterOn == true && (Delta > WaterDurationInSeconds)) {
    TurnOffWater();
    SkipTurningOnIfIjustTurnedItOff = true;
  }

  if (SkipTurningOnIfIjustTurnedItOff == false) {
    //  //Check to see if any of the buttons are pressed
    if (digitalRead(KitchWaterButton) == HIGH || digitalRead(BathroomWaterButton) == HIGH) {
      if (ButtonsReleased == true) { //only do something if buttons have been released between reads
        if (digitalRead(KitchWaterButton) == HIGH && WaterOn == false) {
          WhoTurnedOnTheWater = 2;
        }
        if (digitalRead(BathroomWaterButton) == HIGH && WaterOn == false) {
          WhoTurnedOnTheWater = 1;
        }
        ButtonsReleased = false; //set flag to skip toggle
        if (WaterOn == true) { //toggle the water on and off.
          TurnOffWater();
        }
        else {
          TurnOnWater(false);
        }
      }
    }

    if (digitalRead(BathroomWaterButton) == LOW && digitalRead(KitchWaterButton) == LOW) {
      ButtonsReleased = true;
    }
  }
  //Check the States of pump and or logical state and set the LEDs accordingly
  WaterLEDState();
}

void TurnOnWater(bool SwitchingSources) {
  if (WaterOn == false && HoldingTankAlarm == false) {
    WaterOn = true;
    if (WhoTurnedOnTheWater == 1 && SwitchingSources == false) {
      BathroomWaterTimer = millis();
    }
    if (WhoTurnedOnTheWater == 2 && SwitchingSources == false) {
      KitchenWaterTimer = millis();
    }
    if (WaterSourseSelection == true) {
      digitalWrite(CityWaterValve, HIGH);
    }
    else {
      digitalWrite(WaterPumpOut, HIGH);
    }
    GetWaterState(0);
    GetWaterState(1);
  }
}

void TurnOffWater() {
  digitalWrite(CityWaterValve, LOW);
  digitalWrite(WaterPumpOut, LOW);
  digitalWrite(KitchenWaterButtonLED, LOW);
  digitalWrite(BathroomWaterButtonLED, LOW);
  WaterOn = false;
  GetWaterState(0);
  GetWaterState(1);
}

void WaterLEDState() {
  if (UseWaterPumpSense == true) {
    if ((digitalRead(WaterPumpSense) == LOW && WaterSourseSelection == false) || (WaterSourseSelection == true && digitalRead(CityWaterValve) == LOW)) {
      digitalWrite(KitchenWaterButtonLED, LOW);
      digitalWrite(BathroomWaterButtonLED, LOW);
      WaterOn = false;
    }

    if (digitalRead(CityWaterValve) == HIGH || digitalRead(WaterPumpSense) == HIGH) {
      digitalWrite(KitchenWaterButtonLED, HIGH);
      digitalWrite(BathroomWaterButtonLED, HIGH);
      WaterOn = true;
    }
  }
  else {
    if (WaterOn == true) {
      digitalWrite(KitchenWaterButtonLED, HIGH);
      digitalWrite(BathroomWaterButtonLED, HIGH);
    }
    else {
      digitalWrite(KitchenWaterButtonLED, LOW);
      digitalWrite(BathroomWaterButtonLED, LOW);
    }
  }
}
//------------------------------------------------------------------
//Generator and Energy
//------------------------------------------------------------------
void SetupEnergyMonitor() {
  eic.begin(EnergyMonitorCS, LineFreq, PGAGain, VoltageGain, CurrentGainCT1, 0, CurrentGainCT2);
}

void EnablingPowerToTransformerForEnergyMonitoring() {
  if (EnableACEnergyMonitoring == true) {
    digitalWrite(EnergyMonTransformerEnable, HIGH);
    delay(2500);
    SetupEnergyMonitor();
  }
  else {
    digitalWrite(EnergyMonTransformerEnable, LOW);
  }
}

void EnergyMetering() {
  float voltageA, voltageC, CT1, CT2;
  LastTimeACVoltage = GetCurrentTime();
  unsigned short sys0 = eic.GetSysStatus0(); //EMMState0
  unsigned short sys1 = eic.GetSysStatus1(); //EMMState1
  //unsigned short en0 = eic.GetMeterStatus0();//EMMIntState0
  //unsigned short en1 = eic.GetMeterStatus1();//EMMIntState1

  //if true the MCU is not getting data from the energy meter
  //set all AC Values to 0
  if (sys0 == 65535 || sys0 == 0) {
    BroadCast("R," + GetCurrentTime() + ",Error,Not receiving data from energy meter");
    LastACVoltage = 0;
    LastACCurrent = 0;
    LastPowerFactor = 0;
    LastFreq = 0;
    LastACWatts = 0;
    LastACReactive = 0;
    LastACApparent = 0;
    LastACFundimental = 0;
    LastACHarmonic = 0;
    LastATM90E32Temp = 0;
    LastACRealPower =  0;
    //Attempt to reconnect and setup Energy Monitor
    SetupEnergyMonitor();
  }
  else {
    //get voltage
    voltageA = eic.GetLineVoltageA();
    voltageC = eic.GetLineVoltageC();
    //get current
    CT1 = eic.GetLineCurrentA();
    CT2 = eic.GetLineCurrentC();

    if (LineFreq = 4485) {
      LastACVoltage = voltageA + voltageC;     //is split single phase, so only 120v per leg
    }
    else {
      LastACVoltage = voltageA;     //voltage should be 220-240 at the AC transformer
    }

    if (NumberOfACLegs == 2) {
      LastACCurrent =  CT1 + CT2;
      LastACWatts = (voltageA * CT1) + (voltageC * CT2);
    }
    else {
      LastACCurrent =  CT1;
      LastACWatts = (voltageA * CT1);
      LastPowerFactor = eic.GetTotalPowerFactor();
    }

    // Standard Values to be read and streamed out.
    LastFreq = eic.GetFrequency();
    LastACReactive = eic.GetTotalReactivePower();
    LastACApparent = eic.GetTotalApparentPower();
    LastACFundimental = eic.GetTotalActiveFundPower();
    LastACHarmonic = eic.GetTotalActiveHarPower();
    LastACRealPower =  eic.GetTotalActivePower();

    if (Units == 'I') {
      LastATM90E32Temp = ConvertCtoF(eic.GetTemperature());
    }
    else {
      LastATM90E32Temp = eic.GetTemperature();
    }
  }
}

void GeneratorSensors() {
  float FuelPressureDN = ReadAnalog(25, GenFuelPressure);

  //Sensors i'm using drop out at .5 volts and anything below that will show neg pressure. DN 102 translates to 0.5V
  if (FuelPressureDN > 102) {
    if (Units == 'I') {
      LastGenFuel = (7.5 * ConversionFactor * FuelPressureDN) - 3.75;
    }
    else {
      LastGenFuel = ConvertPSItoKPa((7.5 * ConversionFactor * FuelPressureDN) - 3.75);
    }
  }
  else {
    LastGenFuel = 0.0;
  }

  uint16_t rtd0 = GenHeadR.readRTD();
  //float ratio0 = rtd0;
  //ratio0 /= 32768;
  if (Units == 'I') {
    LastGenHeadRightTemp = ConvertCtoF(GenHeadR.temperature(RNOMINAL, RREF));
  }
  else {
    LastGenHeadRightTemp = GenHeadR.temperature(RNOMINAL, RREF);
  }

  uint16_t rtd1 = GenHeadL.readRTD();
  //float ratio1 = rtd1;
  //ratio1 /= 32768;
  if (Units == 'I') {
    LastGenHeadLeftTemp = ConvertCtoF(GenHeadL.temperature(RNOMINAL, RREF));
  }
  else {
    LastGenHeadLeftTemp = GenHeadL.temperature(RNOMINAL, RREF);
  }

  uint16_t rtd2 = GenEnclosure.readRTD();
  //float ratio2 = rtd2;
  //ratio2 /= 32768;
  if (Units == 'I') {
    LastGenEnclosureTemp = ConvertCtoF(GenEnclosure.temperature(RNOMINAL, RREF));
  }
  else {
    LastGenEnclosureTemp = GenEnclosure.temperature(RNOMINAL, RREF);
  }

  LastTimeGenSensors = GetCurrentTime();
}
//------------------------------------------------------------------
//Tanks
//------------------------------------------------------------------
void HoldingTankMonitoring() {
  //Read Grey and Sewage Tanks at 1hr intervals unless it is at 3/4 full then switch to Constant
  //Read Grey and Sewage Tanks Continuously when WaterOn == True
  if ((millis() - ShitterTankTimer) > 900000 || ShittersGettinFull == true || WaterOn == true) {
    ReadSewageTank();
    if (millis() - HoldingSewageTankPost > 30000) {
      GetSewageLevel(0);
      GetSewageLevel(1);
      HoldingSewageTankPost = millis();
    }
    ShitterTankTimer = millis();
  }

  if ((millis() - GreyTankTimer) > 900000 || GreyGettinFull == true || WaterOn == true) {
    ReadGreyTank();
    if (millis() - HoldingGreyTankPost > 30000) {
      GetGreyLevel(0);
      GetGreyLevel(1);
      HoldingGreyTankPost = millis();
    }
    GreyTankTimer = millis();
  }

  if (ShittersGettinFull == true || GreyGettinFull == true) {
    // Also put in a check for FULL State on either and turn off pump or city water
    if (LastSewageLevel == "Full" || LastGreyWater == "Full") {
      HoldingTankAlarm = true;
      if (TankAlarmOverRide == false) {
        if (WaterOn == true) {
          TurnOffWater();
        }
      }
      ALARM();
    }
    else {
      // if the tanks drop below full make sure the alarm is off
      HoldingTankAlarm = false;
      ResetAlarm();
    }
  }
}
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

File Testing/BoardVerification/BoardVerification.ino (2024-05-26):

#include <LiquidCrystal_I2C.h>
#include <Wire.h>
#include <Adafruit_MAX31865.h>
#include <SPI.h>
#include <RTClib.h>
#include <EEPROM.h>
#include <ATM90E32.h>

/***** CALIBRATION SETTINGS *****/
/*
   4485 for 60 Hz (North America)
   389 for 50 hz (rest of the world)
*/
unsigned short LineFreq = 4485;

/*
   0 for 10A (1x)
   21 for 100A (2x)
   42 for between 100A - 200A (4x)
*/
unsigned short PGAGain = 21;

/*
   For meter <= v1.3:
      42080 - 9v AC Transformer - Jameco 112336
      32428 - 12v AC Transformer - Jameco 167151
   For meter > v1.4:
      37106 - 9v AC Transformer - Jameco 157041
      38302 - 9v AC Transformer - Jameco 112336
      29462 - 12v AC Transformer - Jameco 167151
   For Meters > v1.4 purchased after 11/1/2019 and rev.3
      7611 - 9v AC Transformer - Jameco 157041
*/
unsigned short VoltageGain = 4005;

/*
   25498 - SCT-013-000 100A/50mA
   39473 - SCT-016 120A/40mA
   46539 - Magnalab 100A
*/
unsigned short CurrentGainCT1 = 25498;
unsigned short CurrentGainCT2 = 25498;

//-----------------------------------------------------------
// Serial Communication, UI
//-----------------------------------------------------------
#define USBSerial Serial
#define RS232 Serial2
LiquidCrystal_I2C lcd(0x27, 20, 4);
#define LCDEnable 41
#define LCDPowerOut 23
//-----------------------------------------------------------
// ATM90E32 energy monitor
ATM90E32 eic{}; // Energy Monitor Object
//-----------------------------------------------------------
//-----------------------------------------------------------
// System Level
RTC_DS3231 rtc;
const float ConversionFactor = 5.0 / 1023;
//-----------------------------------------------------------
//-----------------------------------------------------------
//Generator, Energy Monitoring, and Voltage
#define GenFuelPressure A12
#define RTDGenHeadRCS 45
#define RTDGenHeadLCS 47
#define RTDGenEnclosure 49
#define RREF      430.0
#define RNOMINAL  100.0
Adafruit_MAX31865 GenHeadR = Adafruit_MAX31865(RTDGenHeadRCS);
Adafruit_MAX31865 GenHeadL = Adafruit_MAX31865(RTDGenHeadLCS);
Adafruit_MAX31865 GenEnclosure = Adafruit_MAX31865(RTDGenEnclosure);
#define Camper12VoltSensor A0
#define RTCBattery A14
#define EnergyMonitorCS 24
//-----------------------------------------------------------
//-----------------------------------------------------------
//NTC Temperature Sensors
#define FrontACTemp A3
#define BackACTemp A4
#define HallwayTemp A5
#define BathroomTemp A6
#define Freezer A7
#define Refridgerator A8
#define Outside A9
#define BackCabin A10
#define FrontCabin A11
//-----------------------------------------------------------
//-----------------------------------------------------------
//Alarm
#define LEDBacklightOut 8
#define AlarmOut 4
#define WarningLED 5
#define AlarmReset 3
//-----------------------------------------------------------
//-----------------------------------------------------------
//Water Control / Tanks and LPG Tank
#define LPGSensor A1
#define WaterTankSensor A2
#define TankPowerRelay 22
#define WaterSourceSelectionInput 37
#define WaterPumpSense 43
#define KitchWaterButton 18
#define BathroomWaterButton 19
#define CityWaterValve 28
#define KitchenWaterButtonLED 6
#define BathroomWaterButtonLED 7
#define WaterPumpOut 26
//-----------------------------------------------------------
//-----------------------------------------------------------
//Spare IO and Analog
/*
   Spare Inputs are indexed by their number +1 because I don't
   want to start at zero.
*/
const int SpareInputs[] = {35, 33, 31, 29, 27, 25};
const int SpareInputSize = sizeof(SpareInputs) / sizeof(int);
int LastInputState[] = {};
const int SpareOutputs[] = {12, 11, 10, 9, 14, 15};
const int SpareOutputSize = sizeof(SpareOutputs) / sizeof(int);
const int SpareAnalog[] = {13, 15};
const int SpareAnalogSize = sizeof(SpareAnalog) / sizeof(int);
//-----------------------------------------------------------
//-----------------------------------------------------------
// Holding Tank
bool ShittersGettinFull, GreyGettinFull, HoldingTankAlarm = false;
//SewageTankLevelPins
#define S14 48
#define S12 46
#define S34 44
#define S44 42
#define SewagePower 30
//GreyTankLevelPins
#define G14 40
#define G12 38
#define G34 36
#define G44 34
#define GreyWaterPower 32
//-----------------------------------------------------------
void setup() {
  rtc.begin();
  RS232.begin(115200);
  USBSerial.begin(115200);

  pinMode(LCDEnable, INPUT);
  pinMode(LCDPowerOut, OUTPUT);

  for (int i = 0; i <= SpareInputSize; i++) {
    pinMode(SpareInputs[i], INPUT);
    LastInputState[i] = digitalRead(SpareInputs[i]);
  }
  for (int i = 0; i <= SpareOutputSize; i++) {
    pinMode(SpareOutputs[i], OUTPUT);
  }

  pinMode(AlarmReset, INPUT);
  pinMode(WaterSourceSelectionInput, INPUT);
  pinMode(WaterPumpSense, INPUT);
  pinMode(KitchWaterButton, INPUT);
  pinMode(BathroomWaterButton, INPUT);

  pinMode(LEDBacklightOut, OUTPUT);
  pinMode(TankPowerRelay, OUTPUT);
  pinMode(WaterPumpOut, OUTPUT);
  pinMode(AlarmOut, OUTPUT);
  pinMode(WarningLED, OUTPUT);
  pinMode(CityWaterValve, OUTPUT);
  pinMode(KitchenWaterButtonLED, OUTPUT);
  pinMode(BathroomWaterButtonLED, OUTPUT);

  //Sewage Tank
  pinMode(SewagePower, OUTPUT);
  pinMode(S14, INPUT);
  pinMode(S12, INPUT);
  pinMode(S34, INPUT);
  pinMode(S44, INPUT);

  //Grey Water
  pinMode(GreyWaterPower, OUTPUT);
  pinMode(G14, INPUT);
  pinMode(G12, INPUT);
  pinMode(G34, INPUT);
  pinMode(G44, INPUT);

  //Generator
  pinMode(RTDGenHeadRCS, OUTPUT);
  pinMode(RTDGenHeadLCS, OUTPUT);
  pinMode(RTDGenEnclosure, OUTPUT);

  GenHeadR.begin(MAX31865_3WIRE);
  GenHeadL.begin(MAX31865_3WIRE);
  GenEnclosure.begin(MAX31865_3WIRE);

  //Energy
  pinMode(EnergyMonitorCS, OUTPUT);
  eic.begin(EnergyMonitorCS, LineFreq, PGAGain, VoltageGain, CurrentGainCT1, 0, CurrentGainCT2);
}

void loop() {
  //SewAgeTank(); //Pass
  //GreyTank(); //Pass
  //GeneralInputs(); //Pass
  //LCDTesting(); // Need to design and test I2C bus extension buffer. 
  //GeneralOutputs(); //Pass
  //SpareOutputWalk(); // Pass
  //ReadAllInputs(); // Spare Input #1 is failing due to a board defect that is bridging to ground somewhere along the trace between the hex inverter and the MCU pin
  //SpareAnalogRead(); // Pass
  //ReadADCsVoltages(); //Pass
  //ReadOtherTempSensors(); //Pass
  //ReadWaterAndLPG(); // Pass <ay need to install a current limiter on to the 5V out for sensors.
  //readRTD(); //Pass
  //EnergyMonitor();  //Pass
  //GetCurrentTime(); //Pass 

}

void LCDTesting() {
  USBSerial.print("LCDEnable:");
  USBSerial.println(digitalRead(LCDEnable));
  delay(1000);
  USBSerial.print("LCDPowerOut:HIGH");
  digitalWrite(LCDPowerOut, HIGH);
  delay(5000);
  USBSerial.print("LCDPowerOut:LOW");
  digitalWrite(LCDPowerOut, LOW);
  delay(5000);
}
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

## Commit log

2024-05-26 adding 3d Parts
    [EnergyMonitorSpacer.FCStd, PanelStandOff.FCStd]
2024-05-26 adding last part
    [Transformer 157041 mount.FCStd]
2026-09-13 removing I2c LCD display feature.
    This has never worked great or at all because I2c ain't for long runs
